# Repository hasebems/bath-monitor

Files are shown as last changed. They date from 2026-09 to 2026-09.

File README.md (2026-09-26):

# bath-monitor

5人家族の我が家では、お風呂に最後に入った人が湯船の水を抜いて洗うことになっています。しかし、その運用には以下の問題があります。
- まだ入ってない人がいるのに、湯船が空になって洗われていた
- もうみんな入ったのに、まだ入っていない人がいると勘違いして、そのまま朝まで湯船が洗われなかった

その後、入った人は磁石で印を付けるようにしたのですが、その運用は徹底されず、たびたびお風呂に関する問題が起き続けています。  

この bath-monitor はそんな家族の問題を解決するために開発しました。  
bath-monitor は以下の機能を持っています。
- 家族ごとに５つのボタンを搭載。ボタンが押されると LED が点灯し、ボタンごとに異なるメロディを鳴らす
- ボタンの押し間違いがあったら、二秒の長押しで LED は消灯し、キャンセルできる
- 照度センサーを搭載し、脱衣所が明るいか暗いかで誰かが入っていることをセンシングする
- ボタンとセンサーの信号はWi-Fi経由で自宅LAN上のFlaskサーバーに送られ、サーバーはライブダッシュボードを表示
- 携帯や PC でダッシュボードにアクセスすれば、誰が入ったか、今誰かが入っているかをリアルタイムに検知可能

設計の詳細は`docs/design.md`、HTTPの契約(プロトコル)は`docs/protocol.md`、ピン割り当ては`docs/wiring.md`を参照してください。embassy-rpのPIOの不具合の調査記録と回避策は`docs/embassy-rp-pio-drop-bug.md`にまとめています。

## サーバー

```bash
cd server
python -m venv .venv && source .venv/bin/activate
pip install -r requirements.txt
python app.py            # http://<this-machine>:8080
```

テスト: `pytest tests/ -q`(`server/`ディレクトリで、venvを有効化した状態で実行)。

Raspberry Pi上でsystemdサービスとして24時間365日稼働させる方法(`wsgi.py`経由の本番用WSGIサーバー、自動起動・自動再起動)は`docs/deploy.md`を参照してください。

## ファームウェア

`rustup target add thumbv8m.main-none-eabihf`(RP2350はArm Cortex-M33のため)と、書き込み用に`picotool`をPATHに通しておく必要があります(デバッグプローブ不要 — 書き込みはBOOTSEL + `picotool`で行います。`elf2uf2-rs`はRP2350/RP235xでは動作しません)。

```bash
cp firmware/src/secrets.rs.example firmware/src/secrets.rs   # 実際のWi-Fi/サーバー情報を記入
cd firmware
cargo build --release     # コンパイルチェックのみ
cargo run --release       # ビルドし、BOOTSELモードのPico 2 Wにpicotool経由で書き込み
```

ログはUSBシリアル経由(`screen /dev/tty.usbmodemXXXX 115200`)で確認します(RTT/defmtではありません)。

- `XXXX`の部分: Pico 2 WをUSB接続した状態で`ls /dev/tty.usbmodem*`を実行すると確認できる(複数のUSBシリアルデバイスが繋がっている場合は、抜き差し前後で`ls`の差分を見ると確実)
- `screen`の終了方法: `Ctrl-a`の後に`k`を押し、確認プロンプトで`y`を押す(`Ctrl-a` `d`はデタッチのみでプロセスは残るため注意)

## 現在の状況

- サーバーは実機のRaspberry Pi 4上にデプロイ・動作確認済み(ダッシュボードに自宅LAN上のスマートフォンからアクセスできることを確認済み)
- 対象基板は Pico W から Pico 2 W(RP2350) に変更となり、ファームウェアのコードはRP2350向けに移行済みです(`thumbv8m.main-none-eabihf`向けに`cargo clippy`まで通過)
- その後2026-09-19に実機のPico 2 Wへ書き込み、Wi-Fi接続、ボタン(1個目)、MAX98357Aアンプからのメロディ、オンボードLED、サーバーへの送信は動作を確認済み
- 照度センサーは、センサーを覆うとデバウンスされた在室状態が`POST /api/occupancy`で送られ、サーバーのダッシュボードにも在室と表示されることを確認済みです(2026-09-20)
- NeoPixelは、点灯・白の呼吸・長押し取り消しでの消灯を確認済みです。一方、残りのボタン(2〜5個目)と、押した人ごとの色は実機での動作確認がまだです — 確認すべき内容は`docs/design.md`の検証手順の節を参照してください。
- 照度センサーの浴室での明るさ(トリムポットのしきい値)の調整もまだです
- 現在はブレッドボード上での動作確認で、専用の基板を設計中です。基板が完成したら、`docs/design.md`の検証手順に沿って全機能をチェックする予定です

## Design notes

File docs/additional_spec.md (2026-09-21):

# 追加仕様

`docs/design.md`は実装済みの内容(ファイル名や、どのように実装したか)を記述する。このファイルには、今後追加していく外部仕様(何を実現したいか)を追記していく。実装が完了したら、該当項目を`docs/design.md`に反映し、この項目は残したうえで状態を「実装済み」に更新する。

## 雛形

新しい項目を追記するときは、この形式に合わせる(「未決定事項」は無ければ省略してよい)。

```markdown
## <機能名>

**状態:** 未定 / 検討中 / 確定(実装待ち) / 実装済み

**仕様:**
<実現したいことを記述>

**未決定事項:**
- <まだ決まっていない点があれば列挙>
```

---

## オーディオ: `WAVEFORM_BUFFER`への波形書き込み

**状態:** 実装済み(`waveform.rs`/`music.rs`。未決定事項のパラメータ調整とメロディ作成は実機での確認待ち)

**仕様:**

- 波形出力モジュールとして、波形出力用の slot を２個作成する
    - slot は、波形データの先頭から、位相情報に合わせてデータを読み込む
    - slot は、note on message を受信し、これをトリガにして波形を出力する
    - note on message には、pitch, volume, duration の３つのデータがある
        - pitch は、波形を読み込むための1サンプルあたりの位相情報を変更する(69で波形データを一つずつ読む位相となる)。MIDI Note Number 69(=A4=440Hz)を基準に、位相増分 = 2^((pitch - 69) / 12) として計算する
        - volume は、音量で 1-127 の範囲、振幅は (volume/127)^2 とする
        - duration は、音を消し始めるタイミングを制御する
    - slot に note on message が来たら、振幅ゼロから attack rate に従って、少しずつ振幅を上げていく
    - slot が鳴り始めて duration だけ経過したら最大振幅から release rate に従って、少しずつ振幅を下げていく
    - 振幅がある一定値以下(minimum level)になったら、振幅はゼロにする
    - 一つの slot が発音中に新しい note on message が来た時、現在の音を damp rate で急速に消音し、振幅が minimum level 以下になったら、attack rate に従って note on message を開始する
        - damp 中は前の音の pitch で、attack が始まったら新しい pitch で発音する
        - damp rate 中にさらに新しい note on message が来たら、次になる音を新しい note on message に差し替える
    - WAVEFORM_BUFFER のDMA転送が終わったことを確認できたら、AUDIO_BUFFER_SAMPLES 分の二つの slot のバッファの値を足して、その値を WAVEFORM_BUFFER に書き込む
        - 「DMA転送が終わったこと」の確認には Signal を使う。既存の DMA 転送ループ(`i2s.write().await` が返った直後)が Signal を発行し、波形出力モジュールはこれを待ってから次のチャンクを合成・書き込みする。Signal は最新の1回分の通知のみを保持するため、波形出力モジュールが多少速くても遅くても、実際の再生ペースと1:1でずれずに同期できる
    - バッファの値を足した結果がオーバーフローした場合、最大値に張り付く
- 音楽データ再生モジュールを作成する
    - 音楽データは、note on message の集まりであり、time, pitch, volume, duration の４つのデータを複数個持ったものである
        - time: 0 から始まり、再生開始からの時間を表す(1=10msec)
        - pitch: 0-127 の MIDI の Note Number
        - volume: 1-127
        - duration: この note on message が開始してから消音するまでの時間を、time と同じ単位で記述する
    - 読み出したデータは、note on message として二つの slot に交互に送られる
    - 音楽データは全部で５つある
    - このモジュールは、event によって再生開始し、event は 0-4 の値を持っており、その値で音楽データを指定する
    - ボタンを押すと、押したボタン(person_idx、0-4)に対応する音楽データが発音する。つまりボタンごとに別々のメロディが鳴る
    - モジュールが再生中に新しい event が来たら、引数に合った新しい音楽データを再生開始する
        - slot に対して消音するなど、特別な処理は特に行わない
- 波形出力モジュールと音楽データ再生モジュールは、同じ core 内で、別タスクとして実装する
- core0 から core1 に、音楽データ再生モジュールを駆動する event を送る仕組みを作成する(Channelを使用)
    - 実装済み: `music.rs::MELODY_CHANNEL`(`Channel<CriticalSectionRawMutex, usize, 8>`)を新設し、`buttons.rs`のボタン押下処理から person_idx を送信する(長押しによる取り消し時は、`music::CANCEL_MELODY`=5 を送り、専用の取り消し音を鳴らす)。CORE1側では音楽データ再生モジュール(`music.rs`の`music_task`)がこのチャネルを受信して再生を開始する
- 用意するデータ
    - slot 用の波形データ(一波分、サイン波、100サンプル) — 実装済み(`waveform.rs`の`WAVETABLE`)
    - 5つの音楽データ — 実装済み(`music.rs`の`MELODY_0`〜`MELODY_4`)。ただし現状はプレースホルダの短い旋律で、実際の曲ではない
- サンプリング周波数(`AUDIO_SAMPLE_RATE_HZ`)は 44,000Hz とする(一般的なオーディオ規格に合わせる必要がないため、440Hz(MIDI Note 69 = A4)の整数倍を採用)。これにより pitch=69 の波形テーブルがピッチ誤差ゼロで100サンプルぴったりになり、波形データの作成や、将来別の楽器/音色への転用がしやすくなる
- attack/release/damp の動作は、時間に対して一定割合で目標に近づく漸近的カーブとする
    - この「一定割合」は1サンプルごとに適用する(チャンク単位ではない)。RP2350のCPU性能に対して1サンプルごとの演算負荷は十分小さく(1サンプルあたり数千サイクルの余裕がある)、チャンク単位更新による振幅の階段状変化(zipper noise)を避けられるため

**未決定事項:**
- attack rate(現状は`config.rs`の`AUDIO_ATTACK_RATE`=0.01、実機で聴いて調整するまでの仮値)
- release rate(同`AUDIO_RELEASE_RATE`=0.002、仮値)
- damp rate(同`AUDIO_DAMP_RATE`=0.05、仮値)
- minimum level(同`AUDIO_MINIMUM_LEVEL`=0.001、仮値)
- 5つの音楽データの実際の旋律(現状はプレースホルダ)

---

## オンボードLEDのハートビート点滅

**状態:** 実装済み(`wifi.rs`。1Hzの点滅は実機で確認済み。接続試行中の点灯と失敗時の「ピピ」の見え方は未確認)

**仕様:**

- Raspberry Pi Pico 2 W基板上のオンボードLEDで、ファームウェアが動作していることと、Wi-Fi接続の成否を、基板を見るだけで確認できるようにする
- LEDの状態は次のとおりとする

| 状況 | オンボードLED |
|---|---|
| Wi-Fi接続試行(`join`)の実行中 | 点灯したまま |
| 接続試行に成功したあと(接続の監視中) | 1Hz(500ms点灯 / 500ms消灯)の点滅を続ける |
| 接続試行に失敗したあと(次の試行までの待機中) | 「ピピ」(短い点滅2回のあと、しばらく消灯)を繰り返す |

- 失敗の「ピピ」は、接続試行が失敗した直後から始め、次の接続試行が始まる(LEDが点灯に変わる)まで繰り返す。接続に失敗し続けている間は、「点灯 → ピピ、ピピ、…(次の試行まで) → 点灯 → …」の繰り返しになり、成功後の1Hzの点滅とは見分けがつく
- 1Hzの点滅は、接続試行に成功していれば続ける。サーバーとの通信の成否とは無関係で、サーバーが停止していても点滅する
- オンボードLEDはRP2350のGPIOではなくWi-FiチップCYW43439のGPIO0(`WL_GPIO0`)に接続されているため、cyw43の`Control`経由で制御する。外部配線は不要で、`docs/wiring.md`のGPIO割り当てとも競合しない
- 接続試行の実行中に点灯したままにするのは、`join`が`Control`を占有し、完了まで戻らないため。cyw43の`join`自体にはタイムアウトがなく、チップが結果を返さないと永久に戻らないため、ファームウェア側で一定時間(`WIFI_JOIN_TIMEOUT_SECS`)を超えた接続試行を打ち切り、失敗として扱う(この場合の「ピピ」も同じ)。実機で、`join`が戻らずLEDが点灯したままになる現象を確認したための対応
- LEDの制御はCORE0のエグゼキュータ上で、`Control`を所有するタスクが行う。`Control`は`&mut`でしか使えず、Wi-Fiの接続/再接続処理も同じ`Control`を使うため、LED専用タスクは持たず、Wi-Fi管理タスク(下記)が兼ねる。CORE0のエグゼキュータが動かなくなった場合(`panic-halt`によるパニック停止を含む)は、LEDの動きが止まる(点灯か消灯のまま固まる)ため、異常の検知にも使える。CORE1(オーディオ)が動いているかどうかは反映しない

**未決定事項:**
- 接続試行のタイムアウト(`WIFI_JOIN_TIMEOUT_SECS`=20秒)は仮の値。なお、実機で、起動直後の最初の`join`が戻らず、タイムアウト後の2回目で接続できることを確認した(2026-09-19)。戻らない原因(ルーターの認証方式(WPA2/WPA3)や設定との相性、チップの初期化直後の状態など)は未特定で、タイムアウトは症状への対処であり、原因の解消ではない。起動のたびに起きるなら、接続まで約20秒余分にかかる
- 各パターンの時間は仮の値で、実機で見て変更してよい(`config.rs`)。1Hzの点滅(`ONBOARD_LED_BLINK_HALF_PERIOD_MS`=500)、「ピピ」の1回分の点灯/消灯(`ONBOARD_LED_FAIL_FLASH_MS`=100)、「ピピ」の繰り返しの間隔(`ONBOARD_LED_FAIL_PATTERN_GAP_MS`=1600)
- 接続試行に成功したが、まだDHCPが完了していない間(`wifi::is_connected()`はまだ`false`)も、成功として1Hzで点滅する

---

## Wi-Fi接続状態に依存しない動作

**状態:** 実装済み(`wifi.rs`/`outbox.rs`/`http_client.rs`/`status_poll.rs`ほか。実機で確認済み: 接続後のボタン押下がサーバーに届くこと、接続が完了する前の押下が接続後に届くこと、照度センサーによる在室の送信とサーバーのダッシュボードへの反映(2026-09-20)。未確認: 切断後の再接続、オフライン中・サーバー停止中の押下の再送、NeoPixelの同期)

**仕様:**

- 基本方針: すべてのハードウェア(ボタン、NeoPixel、オーディオ、照度センサー、オンボードLED)は、Wi-Fiが接続されているか否かに関わらず、起動直後から動作する。Wi-Fi接続の完了を待って他のタスクの起動を遅らせることはしない(現状は`net::init`が接続完了まで戻らず、その間ボタン等が一切動かないため、これを改める)
- Wi-Fiの接続状態を表すグローバル変数を設ける
    - 「接続済み」は、リンクが上がっており、かつDHCPによるIPアドレス取得が完了した状態とする(`join`に成功しただけでは接続済みとしない)
    - 切断を検知したら「未接続」に戻す
    - 更新するのはWi-Fi管理タスクだけとし、ほかのタスクは読み取るだけにする。送信を行うタスクが、接続済みになるのを待てる形にする
- 未接続の間は、サーバーへのメッセージ(`POST /api/press`、`POST /api/occupancy`、`GET /api/led-state`)を送らない
- Wi-Fi管理タスクを設け、`cyw43::Control`を所有させる
    - 起動時にWi-Fiへ接続する。失敗時は指数バックオフでリトライする(現状の`net.rs`と同じ)
    - 接続後に切断を検知したら再接続する(現状は起動時に1回`join`するだけで、切断後は誰も再接続しないため、ルーターの再起動などで一度切れると電源を入れ直すまで送信できない)
    - オンボードLEDの点滅(前項「オンボードLEDのハートビート点滅」)も兼ねる
- ローカルの動作(NeoPixelの点灯、メロディの再生)は、ネットワークの状態、送信の成否、送信待ちの状態のいずれにも依存しない。ボタン押下の処理はローカルの反応を先に行い、ネットワーク側の処理で待たされないようにする(現状は、送信待ちのチャンネルが満杯になるとボタンタスクが止まり、LEDもメロディも出なくなる)
- ボタン押下の扱い
    - 人ごとの「未送信」の状態(5人分)として保持する。キューではないので溢れず、同じ人の複数回の押下は1つにまとまる(サーバー側も同日中の再押下は冪等)
    - 接続済みの間、送信タスクは未送信の人を順に`POST /api/press`し、2xxが返ったら未送信を下ろす。失敗(接続失敗、タイムアウト、5xxなど)したら未送信のまま残し、一定間隔で再試行する。Wi-Fiは接続済みでサーバーだけが停止している場合も同様に再送する(従来は失敗しても捨てていたため、Wi-Fiが生きていても押下が失われた)
    - 4xxが返った場合(人物IDの不一致など)は、再送しても成功しないため、ログに残して破棄する
    - 押した直後のNeoPixel点灯は、Wi-Fiの状態に関わらず行う
    - `/api/led-state`による同期(Sync)は、未送信の人のLEDを消さない(未送信の操作が求める状態を、サーバー状態より優先して表示する。長押しによる取り消しについては「ボタン長押しによる押下の取り消し」を参照)。これがないと、オフライン中に押した人のLEDが再接続後の同期で消えてしまう
- 在室(照度センサー)の扱い
    - 最後にサーバーへ送信成功した在室状態を保持する。現在値がそれと異なる場合に限り、接続済みの間に現在値を送る
    - オフライン中の途中の変化(例: 入室→退室)は失われる
    - 起動直後は最後に送信した値が不明なため、従来どおり、最初の変化があるまで送らない
    - 4xxが返った場合は、押下と同様にログに残して破棄する
- サーバーへの送信は、必ずタイムアウトして戻ること(相手に届かない場合に、送信タスクが長時間止まらないようにする)
- 許容する制限
    - サーバーが受理したのに応答がタイムアウトした場合、同じ内容を再送する。押下は冪等なので影響はないが、在室は同じ状態が2回記録されうる(サーバーが重複排除をしないため)
    - サーバーは受信した時刻を記録し、基板には時計がないため、オフライン中の押下や在室変化の記録時刻は、送信に成功した時刻になる。深夜0時をまたいで送信された押下は、翌日の記録になる
    - オフラインで起動した場合、既に押した人のNeoPixelも、最初の同期に成功するまでは消灯のままになる(基板に永続ストレージがないため)。その間に再度押しても、同日中の押下は冪等で害はない
    - 送信に必要な`embassy_net::Stack`はWi-Fi接続前に作成できるため、送信/同期タスクは起動時に生成し、接続済みになるまで待機させる

**未決定事項:**(現状の実装での扱いを併記)
- 未送信の押下を保持し続ける期限 — 現状は無期限。長時間オフラインだった後の送信は、実際の押下とは別の日の記録になりうる
- 起動直後の在室状態を、最初の接続時に一度サーバーへ送るかどうか — 現状は送らない。サーバーは重複排除をしないため、送ると再起動のたびに在室ログが1行増える一方、送らないと再起動後に最初の変化があるまでサーバー側の在室状態が実際とずれる可能性がある
- 送信のタイムアウト値、再試行間隔、再接続後のリンク待ち猶予 — 現状は`config.rs`の`SERVER_REQUEST_TIMEOUT_SECS`=10、`SEND_RETRY_INTERVAL_SECS`=5、`WIFI_LINK_UP_GRACE_SECS`=10。いずれも仮の値で、実機で確認して調整する
- 切断後の再接続は、`leave`を挟まずに`join`を呼び直している(実機では未確認。接続試行がタイムアウトした後は`leave`を挟んで再試行し、その2回目で接続できることを実機で確認した)

---

## ボタン長押しによる押下の取り消し

**状態:** 実装済み(`buttons.rs`/`outbox.rs`/`http_client.rs`/`status_poll.rs`/`led.rs`/`music.rs`、サーバーは`POST /api/cancel`。`cargo build --release`/`cargo clippy --release`とサーバーのテストは通過。実機で確認済み: 長押しで取り消し音が鳴り、NeoPixelが消え、Pi上のサーバーのダッシュボードが「Not yet」に戻ること(2026-09-19)。未確認: オフライン中・サーバー停止中の取り消しの再送)。当初は「押した瞬間に登録し、長押しで取り消す」方式だったが、長押しのときも押下のメロディが鳴ってしまうため、「離した時点で登録する」方式に改めた

**仕様:**

- ボタンを押し続けると、その人の「今日の押下」を取り消して、押していない状態に戻せる。押し間違いの訂正や、動作確認中のリセットに使う(従来は翌日0時まで消せなかった)
- 押下として登録するのは、ボタンを押してから`BUTTON_LONG_PRESS_MS`(2000ms)以内に離した時点とする。離したときに、NeoPixel点灯、メロディ、`POST /api/press`を行う(押している間は何も起きない)
- `BUTTON_LONG_PRESS_MS`以上押し続けると、離すのを待たずにその時点で取り消しとみなす。押下のメロディは鳴らさず(取り消し音と混ざらないように)、次だけを行う
    - その人のNeoPixelを消す
    - 取り消し用の音(専用のメロディ`CANCEL_MELODY`、押下のメロディとは別の低く下がる2音)を鳴らす
    - `POST /api/cancel`を送る(サーバーは`last_pressed_at`/`last_pressed_date`をNULLに戻す。冪等)
    - 押したままの間は、離したときに新たな押下と扱わない(離すまで待つ)
- 押していない状態から長押ししても、押していない状態のまま変わらない(取り消し音は鳴る)
- 送信の扱いは押下と同じ。人ごとの未送信の状態は「最後の操作(押下か取り消し)」だけを保持し、未送信の押下の後に取り消しがあれば取り消し1回にまとまる。Wi-Fi非接続時やサーバー停止時も、接続後に再送される
- `/api/led-state`による同期(Sync)は、未送信の操作がある人については、その操作が求めるLEDの状態(押下なら点灯、取り消しなら消灯)を優先する。サーバーの状態は、未送信の操作がない人にだけ反映する
- 4xxが返った場合は、他の送信と同様にログに残して破棄する。古いサーバー(`/api/cancel`が未実装で404を返す)に対しては、取り消しは届かず、次の同期でLEDが再点灯する。サーバーを先に更新してからファームウェアを書き込むこと

**許容する制限:**
- 取り消しが未送信のまま基板を再起動すると、その取り消しは失われる(未送信の状態はRAMのみで保持するため)。押下の場合と同じ

**未決定事項:**
- 長押しの時間 — 現状は`config.rs`の`BUTTON_LONG_PRESS_MS`=2000。仮の値で、実機で確認して調整する。なお押下の反応(LED・メロディ)は離した時点になるため、ボタンを押している間は無反応になる(押し続けても2秒経つまで何も返らない)
- 取り消し音 — 現状は`music.rs`の`MELODY_CANCEL`(プレースホルダ)

---

## NeoPixelの定期書き込みと見え方

**状態:** 実装済み(`led.rs`/`led_pattern.rs`、`config.rs`の`NEOPIXEL_FRAME_INTERVAL_MS`。`cargo build --release`/`cargo clippy --release`は通過。実機で確認済み: 10fpsの書き込み(2026-09-19)。押していない人の白の呼吸(6秒周期)も実機で確認済み(2026-09-19)。その後(2026-09-20)、状態(押下・在室)の保持を`led.rs`から`led_pattern.rs`に移し、イベント用のチャンネル(`LED_CHANNEL`)をやめて、最新の値で上書きする共有状態にし、呼吸の位相をLEDごとにずらして光が流れるようにし、照度センサーが on の間だけ呼吸させるよう変更した — ビルドとclippyは通過、実機では未確認。押した人の人ごとの色も実機では未確認)

**仕様:**

- 動機: 従来はイベントがあったときだけNeoPixelのデータ線に信号が出るため、オシロで1回きりのバーストを捉えるのが難しく、配線や回路の確認がしづらかった。また、ノイズ等でLEDの表示が乱れても、次のイベントまで直らなかった
- NeoPixelは、固定のフレーム周期`NEOPIXEL_FRAME_INTERVAL_MS`(100ms、つまり10fps)で、変化の有無にかかわらず毎フレーム、5個ぶんをチェーンに書き込む。ボタン操作や`/api/led-state`による同期のイベントは、書き込みのタイミングを早めず、人ごとの押下状態を更新するだけにする。その変化は、次のフレーム(最大100ms後)に反映される
- ソフトウェアの構造を、次の2つに分ける。状態の保持を含め、何を見せるかはすべて`led_pattern.rs`にあり、`led.rs`は状態も色も知らない
    - 何を見せるか(`led_pattern.rs`): 状態(人ごとの押下状態、在室状態)と見え方をまとめて担当する。状態は共有データとして持ち(`outbox.rs`と同じく、キューではない)、ボタン・`status_poll`・`occupancy_task`が`set_pressed`/`set_all_pressed`/`set_occupied`で最新の値に上書きする(待たされず、後の書き込みが勝つ)。毎フレーム`frame(now_ms)`が、そのときの状態から1フレームぶんの色を返す。色の決定そのもの(押下状態・在室状態・時刻 → 色)は純粋関数`render`で、ハードウェアには依存しない。色・呼吸の周期・明るさなど、点灯のしかたやそれが依存する状態を変えるときは、このファイルだけを変更する(`config.rs`には見え方に関する定数を置かない)
    - 出力(`led.rs`): PIOによるWS2812への書き込みと、固定周期のフレームループだけ。毎フレーム`led_pattern::frame`が返した色を書く
- 現在の見え方(`led_pattern.rs`)
    - 押下済みの人: 人ごとに決めた色で点灯し続ける(点滅しない)。色は`led_pattern.rs`の表`PRESSED_COLORS`(`config::PEOPLE`と同じ順)で設定する。初期値は、grandpa=青(0,0,48)、grandma=ピンク(40,0,20)、father=緑(0,40,0)、mother=オレンジ(48,16,0)、son=黄(40,28,0)。5色は互いに異なり、押していない人の白と紛らわしくならないよう白っぽい色は避けている
    - まだ押していない人(在室、つまり照度センサーが on のときだけ): 白で、だんだん明るく、だんだん暗くを`BREATH_PERIOD_MS`(6000ms)周期で繰り返す(呼吸)。明るさは三角波を2乗した値(最大は各色`BREATH_PEAK`=16)で、目で見て明るさが均等に変わるようにしている。位相は時刻から計算するため、フレーム周期に依存しない
    - 光が流れる見え方: 呼吸の位相を、チェーンの順(`config::PEOPLE`と同じ順)に、1個ごとに`BREATH_PHASE_STEP_MS`(1000ms)ずつ遅らせる。これにより、明るい部分がLED 0から最後のLEDに向かって横に流れて見える(先頭から末尾までで4秒、周期の約67%)。流れる向きを逆にしたいときは、`render`でLEDの番号を末尾から数える。0にすれば全員が同じ位相に戻る。位相のずれはLEDの位置(チェーン上の番号)で決まるため、間の人が押して点灯していても、残りの人の流れ方は変わらない
    - 不在(照度センサーが off)のとき: まだ押していない人のLEDは消灯する。押した人は、在室かどうかに関わらず、人ごとの色で点灯し続ける(その日の記録であるため)
    - 在室状態の受け渡し: `occupancy_task`が、起動直後の読み取り値(デバウンスなし。`Debouncer`は変化しか返さないため)と、以降のデバウンス済みの変化を、`led_pattern::set_occupied`で渡す。サーバー送信用の`outbox`の扱いは変えない(起動直後の値は、従来どおり送らない)。`led_pattern`の状態は、最初の値が入るまでは不在として扱う

**未決定事項:**
- 押した人の5色の選び方 — 仮の値。実機で見て、区別しやすさと明るさを見て調整する(特にWS2812の青は他の色より暗く見えやすい)
- 呼吸の周期(6秒)・最大の明るさ・最も暗いときの明るさ(現状は完全に消える。最小値を設ける場合は`breath_color`を変える)・位相のずれ`BREATH_PHASE_STEP_MS`(1000ms)は、実機で見て調整する。また、LEDが実際に並ぶ向き(筐体の左右)と、光の流れる向きが合っているかも、筐体ができてから確認する

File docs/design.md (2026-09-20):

# 設計: bath-monitor — 「誰がお風呂に入ったか」を記録する家庭用IoTシステム

## 背景・目的
`bath-monitor`は、浴室の壁に取り付けるパネルで、5個の押しボタン(家族一人につき1個)と1個の在室用照度センサーを備え、Raspberry Pi Pico 2 Wに配線されています。あわせて、各ボタンに対応するNeoPixel(その人が今日押していれば点灯)と、ボタン押下時にその人専用のメロディを鳴らすI2Sアンプ(MAX98357A)+スピーカーも搭載します。ボタンを押すと「この人物は今日入浴した」という記録が残ります(1日単位で冪等、ローカル時刻の深夜0時にリセット。押し間違いなどは、ボタンの長押しで取り消せる) — 目的はあくまで今日誰が押した/押していないかを把握することであり、「最後に入ったのは誰か」を計算することではありません。照度センサーは独立して浴室が現在使用中かどうかを報告し、その入退室の履歴は恒久的にログとして保持されます。Pico 2 Wはどちらの信号も、MQTTではなく単純なHTTP POSTで自宅LAN上のFlaskサーバーに送信し、サーバーは自動更新される単一のHTMLダッシュボードを描画します。

**基板の変更履歴**: 当初の実装(以下参照)は元のPico W(RP2040)を対象としていましたが、ファームウェアを実機に一度も書き込む前の2026-09-03に、対象基板をPico 2 W(RP2350)へ変更する方針となり、同日中にファームウェアのコードもRP2350向けに移行しました(`thumbv8m.main-none-eabihf`向けにビルドとclippyの両方を通過済み。その後、2026-09-19に実機のPico 2 Wへ書き込み、Wi-Fi接続、ボタン、メロディ、オンボードLED、サーバーへの送信の動作を確認済み。未確認の項目は`CLAUDE.md`の「Notes for future work」を参照)。Pico 2 Wはピン互換(GPIO番号が同じ)のため、配線・ピンの計画には影響がありませんでした — マイグレーションの詳細な差分(ターゲットのtriple、`embassy-rp`のfeatureフラグ、ブートイメージ形式、書き込みツール、クロック分周比)については`CLAUDE.md`の「Notes for future work」を参照してください。

初期(Pico W)実装時に開発機(macOS)で使用したツールチェーン: rustc/cargo 1.93.0、`thumbv6m-none-eabi`ターゲットをインストール済み、`elf2uf2-rs`/`flip-link`/`cargo-generate`をPATHに追加(`probe-rs`は未使用 — 書き込みはSWDデバッグではなくBOOTSEL + UF2のドラッグ&ドロップで行う)。Python 3.14.6/pip 26.1.2。RP2350/Pico 2 Wへの移行後: `thumbv8m.main-none-eabihf`ターゲット、書き込みには`elf2uf2-rs`の代わりに`picotool`を使用(`elf2uf2-rs`はRP235x向けの動作するUF2を生成できないため)、リンカとしての`flip-link`はこのターゲットでも引き続き動作することを確認済み。

## リポジトリ構成
1つのリポジトリに2つの独立したプロジェクトが存在します(Cargoワークスペースではなく、Rustのクレートは1つだけ):
```
bath-monitor/
├── CLAUDE.md, README.md, .gitignore
├── docs/design.md           # このファイル(実装済みの内容)
├── docs/additional_spec.md  # 追加していく外部仕様(実装後も項目は残し、状態を更新する)
├── docs/protocol.md         # 正式なHTTP APIの契約(両側の信頼できる情報源)
├── docs/wiring.md           # GPIOピン・PIO/DMAの割り当て
├── docs/deploy.md           # Raspberry Pi 4へのサーバーのデプロイ手順(systemd)
├── firmware/                 # Rust、embassy-rp、独立したクレート
├── schematic/                # KiCadの回路図/基板データ
└── server/                   # Python、Flask
```

## ファームウェア(`firmware/`、Rust + embassy-rp + cyw43)

**主な設計判断:**
- ロギング: `defmt`/RTTではなく`embassy-usb-logger`(USB-CDC)+ `log` — デバッグプローブが手元にないため。ただし書き込みに使うのと同じケーブル経由でUSBシリアルが使える。
- パニックハンドラ: `panic-halt`(RTTベースの`panic-probe`はプローブなしでは意味がないため)。
- 設定: `src/secrets.rs`(gitignore対象、実際のWi-Fi/サーバー情報)+ `src/secrets.rs.example`(コミットされているテンプレート)+ `src/config.rs`(非秘匿情報: 人物リスト、GPIOピン、デバウンス時間など)。
- HTTPペイロード: `heapless::String` + `core::write!`による手作りの小さなJSON(`serde`は使わない — ボディはせいぜい1〜2フィールドのため)。
- タスク間の連携: チャンネルは、CORE1のメロディ再生用の`MELODY_CHANNEL`(コアをまたぐ)だけを、受け取る側の`music.rs`に用意する。NeoPixelの表示に必要な状態(人ごとの押下、在室)は、チャンネルではなく`led_pattern.rs`の共有状態として保持し(最新の値で上書きするだけで、キューも待ちもない)、サーバーへ送るデータも同様に`outbox.rs`の状態(人ごとの未送信の押下/取り消し、在室の現在値/最後に送信した値)として保持し、単一の`sender_task`が`reqwless::HttpClient`を所有して、Wi-Fi接続中に直列で送信する(ロック不要で、自然にPOSTがレート制限される)。ボタン/在室タスクは`outbox`に記録するだけで決してブロックしない。
- Wi-Fi非依存の動作(`docs/additional_spec.md`「Wi-Fi接続状態に依存しない動作」): ボタン、NeoPixel、オーディオ、照度センサーは、`main.rs`でWi-Fiチップの初期化より前に起動し、Wi-Fiの接続状態に関わらず動作する。Wi-Fiの接続状態はグローバル(`wifi::is_connected()`、リンクアップかつDHCP完了で`true`)で表し、Wi-Fi管理タスク`wifi_task`だけが更新する。サーバーへの送信/同期は、これが`true`の間だけ行う。オフライン中(またはサーバー停止中)の押下は`outbox`に未送信として残り、届くまで再送される。同期(`status_poll.rs`)は未送信の人のLEDを消さない。在室は最後に届けた値と異なる場合だけ、現在値を1回送る。
- オーディオ出力: RP2350の2コア目(CORE1)専属で実行(`audio.rs`、`embassy_rp::multicore::spawn_core1`で起動)— PIO2 + DMA_CH3経由のI2S(`embassy_rp::pio_programs::i2s`、GPIO16=BCLK/GPIO17=LRC/GPIO18=DIN、MAX98357Aアンプ宛)によるリアルタイムDMA供給ループを、CORE0側のネットワーク/LED/ボタン処理の遅延から切り離すため。256サンプルの共有バッファ`WAVEFORM_BUFFER`(`CriticalSectionRawMutex` — embassy-rpのSIOハードウェアスピンロック実装によりコア間で安全)の内容を、CORE1が無限ループで読み出しては`i2s.write().await`し続ける設計。バッファへの書き込みは`waveform.rs`が担い、`i2s.write().await`完了ごとに`Signal`(`audio::BUFFER_CONSUMED`)で駆動されることで実際の再生ペースと1:1で同期している(`docs/additional_spec.md`参照)。
- オーディオ合成: 2 slotのサイン波オシレータ+振幅エンベロープ(attack/release/damp、いずれも「1サンプルごとに目標値へ一定割合で近づく」漸近カーブ)からなる`waveform.rs`のシンセと、5つの固定メロディを`music::MELODY_CHANNEL`(ボタン押下由来のperson_idx)をトリガに再生する`music.rs`の2モジュール構成。サンプリング周波数を意図的に非標準の44,000Hz(=440Hz×100)にすることで、MIDI Note 69(A4=440Hz)がピッチ誤差ゼロで100サンプルの波形テーブルにちょうど一致するようにしてある。attack/release/damp rateとminimum levelは`config.rs`に仮値を置いているだけで実機での聴感調整待ち、5つのメロディ自体もプレースホルダ(`CLAUDE.md`のNotes for future work参照)。

**依存クレートのバージョン**(2026-08-30時点でcrates.ioの実際のリリースに対して検証済みで、`firmware/Cargo.lock`で固定。これらのクレートはバージョンによってAPIの形が変わるため、上げる場合は`~/.cargo/registry/src/`の実ソースと突き合わせて確認すること — 詳細は`CLAUDE.md`の「Notes for future work」を参照):
```
embassy-executor 0.10.0, embassy-time 0.5.1, embassy-rp 0.10.0,
embassy-net 0.9.1 (tcp, dns, dhcpv4), embassy-sync 0.8.0, embassy-usb-logger 0.6.0,
cyw43 0.7.0, cyw43-pio 0.10.0, smart-leds 0.4.0,
reqwless 0.14.0, embedded-io-async 0.7.0,
cortex-m 0.7.9, cortex-m-rt 0.7.6, panic-halt 1.0.0,
static_cell 2.1.1, heapless 0.9.3, log 0.4.34, portable-atomic 1.15.0 (critical-section)
```

**モジュール構成:**
- `main.rs` — エグゼキュータのセットアップ、ハードウェア初期化、全タスクのスポーン。起動順は、(1) NeoPixel/オーディオ/在室/ボタンのタスク(Wi-Fiに依存しない)、(2) `net::init`(Wi-Fiチップとスタックの初期化)、(3) `wifi_task`/`sender_task`/`status_poll_task`
- `secrets.rs` / `secrets.rs.example` / `config.rs` — 上記の通り
- `irqs.rs` — `bind_interrupts!`で`PIO0_IRQ_0`/`PIO1_IRQ_0`/`PIO2_IRQ_0`/`DMA_IRQ_0`/`USBCTRL_IRQ`のハンドラを一箇所にまとめて定義(embassy-rpでは全DMAチャンネルが`DMA_IRQ_0`に固定で、チャンネルごとのIRQ選択はできない)
- `debounce.rs` — `buttons.rs`/`occupancy.rs`で共有する`Debouncer`: `wait_for_any_edge()`で変化を検知し、指定時間後もレベルが変わったままなら確定とみなす(チャタリングは静かに無視する)
- `net.rs` — cyw43とembassy-netスタックの初期化のみ(Wi-Fiへの接続はしない)。`(Stack, cyw43::Control)`を返し、`Control`は`wifi_task`に渡される。`Stack`は接続前から作成でき、DHCPはリンクが上がれば自動で進む 注意: embassy-rp 0.10.0のPIOは、利用者数と使用ピンの記録がPIO0/1/2で共有される不具合があり、未使用の`Common`/`StateMachine`をdropすると全PIOのピンが機能なし(NULL)に戻ってしまう(NeoPixelのピンが消えた原因)。そのため、`net.rs`・`led.rs`・`audio.rs`は、未使用の部分を`core::mem::forget`でdropさせない(詳細は`CLAUDE.md`)
- `wifi.rs` — Wi-Fi管理。`cyw43::Control`を所有する`wifi_task`が、`join`(指数バックオフ付きリトライ、一時的なAPの不調から自力で復旧できる必要がある — 動かなくなった基板をデバッグするプローブがないため)、接続後のリンク/DHCP状態の監視、切断時の再`join`を行い、その結果をグローバルの`is_connected()`(`AtomicBool`)に反映する。未接続→接続済みになるたびに、`WIFI_UP`(`status_poll.rs`用)と`outbox::WORK`(`sender_task`用)を`Signal`する。オンボードLED(`WL_GPIO0`、Pico 2 WのオンボードはRP2350のGPIOではなくCYW43439のGPIO0で、`Control`経由でしか制御できず、`join`も同じ`Control`を`&mut`で使うためこのタスクが兼ねる)は`join`の結果を表示する。`join`実行中は点灯を保持し(`join`は完了まで戻らないうえcyw43側にタイムアウトがないため、`config::WIFI_JOIN_TIMEOUT_SECS`(20秒)を超えたら打ち切って失敗として扱い、`leave`してから再試行する)、成功後の接続監視中は`config::ONBOARD_LED_BLINK_HALF_PERIOD_MS`(500ms)ごとに反転して1Hzで点滅し、失敗後のバックオフ待ちの間は「ピピ」(`ONBOARD_LED_FAIL_FLASH_MS`=100msの点灯/消灯を2回、`ONBOARD_LED_FAIL_PATTERN_GAP_MS`=1600msの消灯を挟んで繰り返す)を出して、次の`join`で点灯に戻る。CORE0のエグゼキュータ上で動くため、CORE0が停止/パニックするとLEDの動きが止まり、生存確認になる。CORE1(オーディオ)やサーバー通信の成否は反映しない
- `outbox.rs` — サーバーへ届けるべきものの状態。押下/取り消しは人ごとに「状態語(操作のたびに増えるカウンタ+取り消しフラグ)」と「サーバーが受理した状態語」(不一致=未送信で、フラグが押下か取り消しかを表す。送信中に操作されても取りこぼさず、最後の操作だけが送られる)、在室は「最新の確定値」と「最後に届けた値」。`mark_press`/`mark_cancel`/`set_occupancy`は`WORK`(`Signal`)を発行するだけで決してブロックしない。`next()`が次に届けるものを返し、`complete()`で完了にする
- `buttons.rs` — `Debouncer`を使った5個の非同期タスク(pool_size=5)、ピンごとに50msでデバウンスし、押下確定後、`config::BUTTON_LONG_PRESS_MS`(2000ms)以内に離されたら(`with_timeout`で`Debouncer::debounce`を待つ形)押下として`outbox::mark_press`(サーバー送信用の記録、非ブロッキング)、`led_pattern::set_pressed(idx, true)`(LED点灯用)、`MELODY_CHANNEL`へのperson_idx送信(そのボタンに対応するメロディの再生トリガ、`docs/additional_spec.md`参照)を行う。離されないまま経過したら取り消しとみなし(押下メロディは鳴らさない)、`outbox::mark_cancel`、`led_pattern::set_pressed(idx, false)`(LED消灯)、`MELODY_CHANNEL`への`CANCEL_MELODY`送信を行って、離すまで待つ
- `occupancy.rs` — 照度センサーの読み取り(要件通りデジタル`Input`による2値信号)、`Debouncer`でしきい値付近のチャタリングを排除(約2000ms)してから`outbox::set_occupancy`で最新値を記録し、同じ値を`led_pattern::set_occupied`でNeoPixelにも渡す(起動直後の読み取り値も、デバウンスなしでNeoPixelにだけ送る)
- `http_client.rs` — 単一の`reqwless::HttpClient`を所有する`sender_task`が、`outbox::WORK`で起こされ、`wifi::is_connected()`の間だけ`outbox::next()`の内容を`/api/press`・`/api/cancel`に`{"person":"grandpa"}`、`/api/occupancy`に`{"occupied":true}`としてPOSTする。1リクエストは`config::SERVER_REQUEST_TIMEOUT_SECS`(10秒)でタイムアウトする。2xxなら完了、4xx(人物ID不一致など)はログに残して破棄、それ以外(接続失敗、タイムアウト、5xx)は未送信のまま`config::SEND_RETRY_INTERVAL_SECS`(5秒)後に再試行する
- `led.rs` — WS2812 NeoPixelチェーン(PIO1 + DMA_CH2、GPIO15、`config::PEOPLE`と同順)を所有し、出力だけを担当する。書き込みは`config::NEOPIXEL_FRAME_INTERVAL_MS`(100ms、10fps)の固定周期で、変化がなくても毎フレーム5個ぶんを、`led_pattern::frame`が返した色で書く(`Timer::at`で次のフレームの時刻まで待つ。状態の変化で書き込みが早まることはなく、変化は1フレーム以内に反映される)。色や点滅だけでなく、状態がどこから来るかも扱わず、すべて`led_pattern`に任せる
- `led_pattern.rs` — NeoPixelに何を見せるかのすべて。人ごとの押下状態と在室状態を、共有の状態(`Mutex<CriticalSectionRawMutex, Cell<…>>`)として持つ。更新は、最新の値で上書きする関数を直接呼ぶだけ(キューではないので、待たされることも溢れることもなく、後の書き込みが勝つ): `set_pressed(idx, bool)`(ボタンの押下/取り消し)、`set_all_pressed`(`status_poll.rs`から全員分を一括反映 — サーバーの日次リセット後にLEDを消す役目もこれが担う)、`set_occupied`(在室状態)。`frame(now_ms)`が、そのときの状態から1フレームぶんの色を返す。色の決定は、押下状態・在室状態と時刻だけから決まる純粋関数`render`(ハードウェア非依存)。現状は、押下済みの人が人ごとの色(表`PRESSED_COLORS`、`config::PEOPLE`と同順)で点灯し続け、押していない人は、在室(照度センサーが on)のときだけ、白で6秒周期(`BREATH_PERIOD_MS`)でだんだん明るく/暗くを繰り返し(呼吸の位相は`now_ms`から計算し、LEDごとに`BREATH_PHASE_STEP_MS`ずつずらして光が横に流れるように見せる)、不在のときは消灯する。色や周期などの見え方に関する定数は`config.rs`ではなくこのファイルに置き、見え方を変えるときは、このファイルだけを変更する
- `status_poll.rs` — Wi-Fi接続中に`GET /api/led-state`を`config::LED_SYNC_INTERVAL_SECS`ごと(および接続が復帰した直後)にポーリングし、結果を`led_pattern::set_all_pressed`で反映(リクエストは`SERVER_REQUEST_TIMEOUT_SECS`でタイムアウト)。サーバーがまだ知らない操作(`outbox`で未送信の押下/取り消し)がある人は、サーバーの答えではなくその操作が求める状態(押下なら点灯、取り消しなら消灯)のままにする。これがサーバー側の日次リセットや、ファームウェア再起動後の状態復元を反映させる仕組み
- `audio.rs` — CORE1専属でMAX98357A向けI2S出力(PIO2 + DMA_CH3、GPIO16=BCLK/GPIO17=LRC/GPIO18=DIN、`embassy_rp::pio_programs::i2s`)を行う。`embassy_rp::multicore::spawn_core1`でCORE1を起動し、`core1_task`(256サンプルの共有バッファ`WAVEFORM_BUFFER`を無限ループで読み出し`i2s.write().await`し続ける)、`waveform::waveform_task`、`music::music_task`の3つをその上にスポーンする。`core1_task`は`i2s.write().await`完了ごとに`Signal`(`BUFFER_CONSUMED`)を発行し、`waveform_task`はこれを待ってから次のチャンクを合成・書き込みすることで、実際の再生ペースと1:1で同期する
- `waveform.rs` — 「波形出力モジュール」(`docs/additional_spec.md`)。100サンプルのサイン波テーブル(`AUDIO_SAMPLE_RATE_HZ`=44,000Hzで、MIDI Note 69=A4=440Hzがピッチ誤差ゼロでちょうど1周する長さ)と、MIDIノート番号ごとの固定小数点(Q16)位相増分テーブル`PITCH_STEP_Q16`(`2^((pitch-69)/12)`から生成)を持つ。2つのslot(`Slot`構造体、状態はIdle/Attack/Release/Damp)を`waveform_task`が所有し、`SLOT_CHANNELS[0]`/`[1]`(`music.rs`から送られる`NoteOn`)を受けて発音、`BUFFER_CONSUMED`で駆動されるたびに`AUDIO_BUFFER_SAMPLES`分を1サンプルずつ合成・加算(オーバーフロー時は`i16`範囲にクランプ)して`WAVEFORM_BUFFER`に書き込む
- `music.rs` — 「音楽データ再生モジュール」(`docs/additional_spec.md`)。`config::PEOPLE`と同順の5つの固定メロディ(`NoteEvent{time, pitch, volume, duration}`の配列、現状はプレースホルダの短い旋律)を持つ`music_task`が、`MELODY_CHANNEL`(この`music.rs`が持つ、`Channel<CriticalSectionRawMutex, usize, 8>`。CORE0のボタンタスクから、押されたボタンのperson_idx(取り消し時は`CANCEL_MELODY`=5)を受け取る、唯一のチャンネルでコアをまたぐ。NeoPixelの状態は`led_pattern.rs`に、サーバー送信用のデータは`outbox.rs`にある)から受け取ったperson_idxでメロディを選び直し、`embassy_time::with_timeout`で次のノートの時刻まで待機しながら`waveform::SLOT_CHANNELS`の2つに交互に`NoteOn`を送出する。再生中に新しいイベントが来たら、鳴っている音は特に消音せずに新しいメロディの先頭から再生を始める

**ビルド/書き込み(移行後のRP2350/Pico 2 W):** `.cargo/config.toml`で`target = "thumbv8m.main-none-eabihf"`、`runner = "picotool load -u -v -x -t elf"`を設定(`elf2uf2-rs`のUF2出力はRP235xでは動作しないことをembassy-rs/embassy#4322で確認済み)。リンカには`flip-link`を使用(スタックオーバーフローのガードページ — デバッガがない環境では有用。このターゲットでも問題なくリンクできることを確認済み)。`memory.x`はRP2350のブートレイアウト(RP2040のBOOT2領域の代わりに`.start_block`/`.bi_entries`/`.end_block`セクション)を使用しています — `embassy-rp`の`rp235xa`featureが必要な`IMAGE_DEF`ブートブロックを自動的に生成してくれるため、`main.rs`側の変更は不要でした。`cargo run --release`でビルド → BOOTSELモードのPico 2 Wに`picotool`経由で書き込みます。

## サーバー(`server/`、Python + Flask)

**構成:** `Flask==2.2.5`(`Werkzeug==2.2.3`、Jinja2を同梱)に加え、本番用WSGIサーバーとして`waitress==2.1.2`を使用 — このアプリはRaspberry Pi 4上でsystemd経由で24時間365日稼働するため(`docs/deploy.md`参照)、実際にデプロイされるのは`wsgi.py`/waitressの組み合わせです。本番のPiはPython 3.7.3(Raspberry Pi OS Buster)のため、これらは3.7をサポートする最後のリリースに固定してあり、コード側も`from __future__ import annotations`で3.8以降専用の型ヒント構文(`X | Y`、`list[X]`)を避けています(`docs/deploy.md`参照)。`app.py`のFlask開発用サーバー(`python app.py`)はローカル開発用としてのみ残しています。永続化は標準ライブラリの`sqlite3`を使用(スキーマは小さなテーブル2つのみで、ORMは不要)。

**スキーマ(`schema.sql`):**
```sql
CREATE TABLE press_status (
    person TEXT PRIMARY KEY,
    last_pressed_at TEXT,        -- ISO8601、一度も押されていなければNULL
    last_pressed_date TEXT       -- 'YYYY-MM-DD'形式、リセット処理の判定に使用
);
CREATE TABLE occupancy_log (
    id INTEGER PRIMARY KEY AUTOINCREMENT,
    occupied INTEGER NOT NULL CHECK (occupied IN (0,1)),
    changed_at TEXT NOT NULL     -- ISO8601、追記専用で、削除されることはない
);
```
`press_status`は起動時に`config.PEOPLE`から(`INSERT OR IGNORE`で)初期投入されます — 家族の追加は設定変更+再起動で対応します。現在の在室状態は、専用の「現在の状態」テーブルを持たず、`occupancy_log`の最新行そのものとします(こうすることで状態のズレを防いでいます)。

**日次リセット(スケジューラなし):** 読み書きのたびに`last_pressed_date`を`date.today()`(サーバーのローカル時刻。UTCのクラウドインフラではなく自宅LAN上で動いているため、標準ライブラリの`datetime`のみで`pytz`/`zoneinfo`は不要)と比較します。`pressed_today = (last_pressed_date == today)`。押下時の書き込みは無条件のupsertであり、同日中の再押下は害のない冪等な上書きになります。

**ルーティング(`app.py`、アプリファクトリパターン):**
| メソッド | パス | 用途 |
|---|---|---|
| POST | `/api/press` | `{"person": "<id>"}` → `config.PEOPLE`に対して検証(未知なら400)、`press_status`をupsert |
| POST | `/api/cancel` | `{"person": "<id>"}` → 検証は`/api/press`と同じ。`press_status`の`last_pressed_at`/`last_pressed_date`をNULLに戻す(冪等。ボタン長押しによる取り消し) |
| POST | `/api/occupancy` | `{"occupied": true\|false}` → `occupancy_log`に追記(サーバー側での重複排除はせず、ファームウェア側のデバウンスを信頼する) |
| GET | `/api/status` | JSONスナップショット: 人物ごとの`pressed_today`/`last_pressed_at`、現在の`occupied`/`occupied_since` |
| GET | `/api/led-state` | `config.PEOPLE`と同順で1人1文字(押下済みなら`1`、そうでなければ`0`)の`"10100"`形式を`text/plain`で返す — ファームウェアがNeoPixelを同期するための軽量な表現(`docs/protocol.md`参照) |
| GET | `/` | `/api/status`と同じ`db.get_status()`のデータを使って`templates/status.html`を描画 |

`db.py`は`init_db()`、`get_status()`、`get_led_state()`、`record_press()`、`cancel_press()`、`record_occupancy()`を公開しており、ルート側は薄いまま(パース → 呼び出し → 返却/描画)にしています。`get_led_state()`は`get_status()`の結果から組み立てており、`/`・`/api/status`・`/api/led-state`はすべて同じ`get_status()`を情報源にしています(クエリ処理を各ルートに重複させない)。戻り値の型は`models.py`のdataclass(`PersonStatus`/`Status`)、設定値(`PEOPLE`、ホスト/ポート、DBパス)は`config.py`にあります。

**ページ:** `templates/base.html` + `status.html`、`<meta http-equiv="refresh" content="5">`(自宅LAN向けのダッシュボードなのでJS/WebSocketは不要) — 5人分を色付きのピル(押した/押していない)で表示し、在室状態のバナーを1つ表示(在室中/不在 + 開始時刻)。`static/style.css`で最小限のスタイリングを行います。

## 作成されたファイル
```
firmware/Cargo.toml, Cargo.lock, .cargo/config.toml, memory.x, build.rs
firmware/cyw43-firmware/   (cyw43のファームウェア/CLM/nvramのBLOB)
firmware/src/{main,secrets.rs.example,config,irqs,debounce,net,wifi,outbox,buttons,occupancy,http_client,led,led_pattern,status_poll,audio,waveform,music}.rs
                            (secrets.rsは実際のWi-Fi情報を入れるgitignore対象のファイル)
server/{requirements.txt,config.py,schema.sql,db.py,models.py,app.py,wsgi.py}
server/deploy/bath-monitor.service
server/templates/{base,status}.html, server/static/style.css
server/tests/{conftest.py,test_api.py}
server/data/.gitkeep   (bath_monitor.dbは実行時状態のためgitignore対象)
docs/{design,additional_spec,protocol,wiring,deploy}.md
schematic/             (KiCadの回路図/基板データ)
README.md, .gitignore  (firmware/target/, firmware/src/secrets.rs, __pycache__/, .venv/, server/data/*.db, .pytest_cache/, schematic/bath-monitor-backups, .DS_Store)
```

## 検証手順
**サーバー(ハードウェア不要):**
```bash
cd server && python -m venv .venv && source .venv/bin/activate && pip install -r requirements.txt
python app.py
# 別のターミナルで:
curl -X POST localhost:8080/api/press -H 'Content-Type: application/json' -d '{"person":"grandpa"}'
curl -X POST localhost:8080/api/cancel -H 'Content-Type: application/json' -d '{"person":"grandpa"}'
curl -X POST localhost:8080/api/occupancy -H 'Content-Type: application/json' -d '{"occupied":true}'
curl localhost:8080/api/status
open localhost:8080/
```
併せて確認すること: 未知の人物 → 400、不正なリクエストボディ → 400、sqliteファイル内の`last_pressed_date`を手動で過去日付にしてリセット処理を確認し、`/api/status`が`false`に切り替わることを確認する。`pytest server/tests/`を実行する。

**ファームウェア(書き込み後):** PicoをBOOTSELモードにして`cargo run --release` → USBシリアル端末を開く(`screen /dev/tty.usbmodemXXXX 115200`) → Wi-Fi接続とIPのログを確認し、その後、物理的なボタン押下によってサーバー側で`POST /api/press 200`が発生すること(Flaskのリクエストログで確認可能)、ダッシュボードのピルが1回の更新サイクル以内に緑色に切り替わることを確認する。照度センサーを覆う/覆いを外すを行い、実際の状態遷移1回につき、チャタリングによる大量発生ではなく、デバウンス済みの`occupancy_log`の行がちょうど1行だけ記録されることを確認する。オンボードLEDは、cyw43の初期化後にWi-Fi接続試行(`join`)中は点灯し、接続に成功したら約1Hzで点滅すること(サーバーを止めても点滅が続くこと)、接続に失敗したら(`secrets.rs`のSSIDをわざと間違えるなど)「ピピ」と短く2回光ることを繰り返し、次の試行で点灯に戻ることを確認する。Wi-Fi非依存の動作として、`secrets.rs`のSSIDをわざと間違えて(またはルーターを止めて)Wi-Fiに接続できない状態にしても、ボタンでNeoPixelが点灯しメロディが鳴ること、その状態で押した後にWi-Fiを復旧させると自動で再接続し、押した内容がサーバーに反映されLEDも消えないこと、接続中にルーターを止めて戻すと切断後に自動で再接続すること、Wi-Fiは生きたままサーバーだけ止めて押しても、サーバー復旧後に反映されることを確認する。ボタンを押して2秒以内に離すと、該当する人物のNeoPixelが点灯してメロディが鳴る(押している間は鳴らない)ことも確認する。長押し(約2秒)では、押下メロディは鳴らずにNeoPixelが消えて取り消し音だけが鳴り、サーバー側で`POST /api/cancel 200`が発生してダッシュボードが「Not yet」に戻ること、離したときに新たな押下として扱われないこと、Wi-Fi未接続で取り消して復旧させるとLEDが再点灯せず、サーバーにも反映されることを確認する。オーディオ(`audio.rs`/`waveform.rs`/`music.rs`)は、各ボタンを押してそれぞれ異なるメロディがスピーカーから鳴ること、再生中に別のボタン(または同じボタン)を押すと途中から新しいメロディに切り替わること、音割れがないことを確認する(メロディはプレースホルダで、attack/release/damp rateやminimum levelも仮値のため、聴感による調整もここで行う)。スピーカー接続前は、ロジックアナライザ等でGPIO16/17(BCLK/LRCLK)に常時クロックが出ていること、ボタン押下時にGPIO18(DIN)へ波形が出ることを確認する。

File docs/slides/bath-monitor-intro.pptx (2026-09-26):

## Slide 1

bath-monitor

家族の「誰がお風呂に入ったか」を見える化する家庭用IoTシステム

プロジェクト紹介 ― 課題・仕様・全体システム構成
2026年9月

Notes: bath-monitor の紹介です。今回はハードウェア(専用基板)がまだ完成していないため、何を解決したいのか、どんな仕様なのか、全体のシステム構成までをお話しします。

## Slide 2

我が家のお風呂のルールと困りごと

5人家族 ― 「最後に入った人が湯船の水を抜いて洗う」

ルール

最後に入った人が
湯船の水を抜いて洗う

でも「自分が最後かどうか」が
分からない

早すぎた

まだ入っていない人がいるのに、湯船が空になって洗われていた

1

忘れられた

もう全員入ったのに「まだ誰か入っていない」と思い込み、朝まで湯船が洗われなかった

2

続かなかった

入った人が磁石で印を付ける運用も試したが徹底されず、問題が起き続けている

5人

3

2

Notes: 我が家は5人家族で、最後に入った人が湯船の水を抜いて洗うルールです。ところが、誰が入ったかを誰も正確に把握できていないため、2種類の失敗が繰り返されていました。

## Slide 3

解決したいこと

「今日、誰がもう入ったか」を家族全員が確実に分かるようにする

記録が手間にならない

入ったら浴室のボタンを
1回押すだけ。
磁石のような「つい忘れる」
操作を減らす

1

その場で一目で分かる

押した人のLEDが点灯。
押した瞬間にメロディも鳴り
「押した」ことが分かる

2

家のどこからでも分かる

スマホやPCのブラウザで
誰が入ったか・今入浴中か
をリアルタイムに確認

3

ゴール：「全員のLEDが点いた」＝自分が最後。迷わず湯船を洗える

3

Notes: 目的は「最後に入ったのは誰か」を計算することではなく、今日誰が押した/押していないかを把握すること。全員分点いていれば自分が最後だと分かります。

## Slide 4

使い方

浴室の壁に付けたパネルのボタンを押すだけ

お風呂に入る

脱衣所の照明が点くと
照度センサーが
「入浴中」を検知

1

自分のボタンを押す

自分のLEDが自分の色で
点灯し、自分専用の
メロディが鳴る

2

間違えたら長押し

2秒の長押しで取り消し。
LEDが消え、
取り消し音が鳴る

3

毎日0時にリセット

日付が変わると
全員が「未入浴」に戻る

4

いつでも：スマホ/PCのブラウザでダッシュボードを開けば、誰が入ったか・今誰かが入浴中かが分かる

見る

4

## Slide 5

仕様：浴室パネル

浴室の壁に取り付ける箱に、ボタン・LED・センサー・スピーカーをまとめる(完成予想図)

スピーカー

ボタンを押すと人ごとに違うメロディ、取り消しでは取り消し音(I2Sアンプ MAX98357A)

Wi-Fi

自宅LANのサーバーへ送信。切れていてもパネルは単体で動く

フルカラーLED × 5

押した人：自分の色で点灯
まだの人：入浴中は白くゆっくり明滅。誰もいなければ消灯

USB

USBで給電。箱の中にはマイコン Raspberry Pi Pico 2 W(Wi-Fi内蔵)

ボタン × 5(1人1個)

押して離すと入浴済みに。長押し(2秒)で取り消し

照度センサー

脱衣所の明るさで「入浴中」を判定。明るさのしきい値は調整できる

完成予想図(イメージ)

5

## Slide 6

仕様：サーバーとダッシュボード

自宅の Raspberry Pi 4 で24時間稼働。記録を保存し、見やすく表示する

Bath Monitor

入浴中(21:32〜)

ダッシュボードのイメージ

1日単位で記録

同じ日に何度押しても記録は1回分。取り消しは長押しで

1

おじいちゃん

入浴済み

0時に自動リセット

日付を比較するだけの仕組みで、タイマー処理なしでリセット

2

おばあちゃん

まだ

お父さん

入浴済み

入退室の履歴を保存

在室/不在の変化は削除せず追記し、いつ入浴していたかを残す

3

お母さん

入浴済み

息子

まだ

5秒ごとに自動更新

自宅LAN内のスマホ/PCのブラウザで開くだけ。アプリ不要

4

6

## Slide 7

全体システム構成

浴室パネル・自宅サーバー・ブラウザの3つを自宅LANでつなぐ

浴室パネル

Raspberry Pi Pico 2 W(Rust)

- ボタン × 5
- 照度センサー
- フルカラーLED × 5
- アンプ + スピーカー
- Wi-Fi(CYW43439)

自宅サーバー

Raspberry Pi 4(Python / Flask)

- HTTP API を受け付け
- SQLite に記録
- 0時で日次リセット
- ダッシュボード(HTML)を配信
- systemd で自動起動・再起動

スマホ / PC

ブラウザのみ(アプリ不要)

- 誰が入浴済みか
- 今、入浴中か
- 5秒ごとに自動更新

パネル → サーバー：ボタン押下/取り消し・在室の変化を送信(HTTP POST)

サーバー → パネル/ブラウザ：LED状態の定期同期・ダッシュボード表示(HTTP GET)

7

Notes: MQTTなどは使わず、単純なHTTPだけでつなぎます。すべて自宅LAN内で完結し、クラウドは使いません。パネルは定期的にサーバーからLED状態を取得するので、0時のリセットや再起動後もLEDが正しい状態に戻ります。

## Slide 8

浴室パネルの内部構成

2つのCPUコアで役割を分担し、Wi-Fi通信と音の再生が互いに邪魔しない

押しボタン × 5

GPIO 2〜6

Pico 2 W(RP2350)

CORE0

- ボタン/センサーの読み取り
- LED描画(10fps)
- Wi-Fi接続管理・HTTP送信
- サーバーとのLED状態同期

CORE1(音専用)

- メロディ再生 → シンセ合成
- → I2Sへ途切れず出力

フルカラーLED × 5

GPIO 15 / PIO1

照度センサー

GPIO 26

ボタンを押したときの点灯とメロディは、Wi-Fiを使わずパネルの中だけで完結する

アンプ MAX98357A
+ スピーカー

GPIO 16〜18 / PIO2(I2S)

Wi-Fiチップ CYW43439

PIO0(SPI)

8

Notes: PIO(プログラマブルI/O)を3ブロックすべて使い、Wi-Fi・LED・音声をそれぞれDMAで駆動しています。音声はCORE1専用にして、ネットワーク処理の遅延で音が途切れないようにしています。

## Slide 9

通信の取り決め(HTTP API)

パネルとサーバーは JSON / テキストの小さな HTTP リクエストだけでやりとりする

メソッド | パス | 内容 | 意味
POST | /api/press | {"person":"father"} | ボタンを押して離した(入浴済みにする)
POST | /api/cancel | {"person":"father"} | 2秒長押し(その日の入浴記録を取り消す)
POST | /api/occupancy | {"occupied":true} | 在室状態が変化した(履歴に追記)
GET | /api/led-state | → "10110" | 1人1文字でLED状態を返す(パネルが定期取得)
GET | /api/status | → JSON | 全員の状態と在室状態のスナップショット
GET | / | → HTML | ダッシュボード(5秒ごとに自動更新)

- パネル→サーバーの送信は、届くまで(2xx応答まで)再送。オフライン中の操作も後で必ず届く
- 人の並び順(おじいちゃん・おばあちゃん・お父さん・お母さん・息子)はパネルとサーバーで共通

9

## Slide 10

設計のポイント

家族が毎日使うものなので「止まらない・取りこぼさない」を重視

Wi-Fiが切れても使える

ボタン・LED・メロディ・センサーは Wi-Fi より先に起動。通信状態に関係なく動作する

1

操作を取りこぼさない

サーバーに届けるべき操作をパネル内に保持し、つながったら届くまで再送。人ごとに最新の操作だけを送る

2

サーバーと自動で一致

パネルは定期的にLED状態をサーバーから取得。0時のリセットや再起動後も正しい表示に戻る

3

音が途切れない

音の合成と出力はCORE1専用。通信処理の遅れが音に影響しない

4

10

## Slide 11

使っている技術

ファームウェア・サーバー・基板の3つを1つのリポジトリで管理

ファームウェア

Rust(no_std)

- embassy-rp:非同期ランタイム
- cyw43 / embassy-net:Wi-Fi・TCP/IP
- reqwless:HTTPクライアント
- PIO + DMA:LED・I2S・Wi-Fi SPI
- picotool で書き込み

サーバー

Python

- Flask:Web API・画面
- SQLite:データ保存(テーブル2つ)
- waitress:本番用WSGIサーバー
- systemd:自動起動・再起動
- pytest:自動テスト

ハードウェア

KiCad

- Raspberry Pi Pico 2 W
- NeoPixel(WS2812)× 5
- MAX98357A I2Sアンプ
- CdS + LM393 光検出モジュール
- 専用基板を設計中

11

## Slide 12

現在の状況と次のステップ

済

済

済

今

次

次

設計・実装

ファームウェア/サーバー
一通り実装

サーバー稼働

Raspberry Pi 4で稼働
スマホから閲覧OK

ブレッドボード検証

Wi-Fi・送信・ボタン・
音・LED・センサー

専用基板の設計

KiCadで回路図・
基板データを作成中

基板製作・全機能確認

5個のボタン、音量、
人ごとの色など

浴室に設置

センサーのしきい値を
実際の明るさで調整

基板が完成したら全機能をチェックし、浴室に設置して家族で使い始める予定です

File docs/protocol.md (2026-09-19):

# HTTPプロトコル

`firmware/`(クライアント)と`server/`(Flaskアプリ)間の正式な契約(コントラクト)。両者はこの内容に一致させる必要があります — ファームウェア側の`PEOPLE`/`config.rs`の人物IDは、`server/config.py`の`PEOPLE`リストと完全に一致していなければなりません。

ベースURL: `http://<server-host>:8080`(ファームウェア側は`secrets.rs`の`SERVER_BASE_URL`、サーバー側は`server/config.py`の`HOST`/`PORT`で設定)。

## `POST /api/press`

デバウンス処理済みのボタン押下を、サーバーへ届けるために送信されます。Wi-Fiが切れている間やサーバーが応答しない間の押下は、ファームウェア側で「未送信」として保持され、2xxが返るまで再送されます(同じ人の複数回の押下は1回にまとまります)。サーバー側は同日中の再押下を冪等に扱うため、再送されても問題ありません。4xxが返った場合は、再送しても成功しないため破棄します。

サーバーは受信した時刻を記録するため、オフライン中の押下の記録時刻は、実際の押下時刻ではなく、送信に成功した時刻になります(深夜0時をまたぐと翌日の記録になります)。

リクエストボディ:
```json
{ "person": "grandpa" }
```

レスポンス `200 OK`:
```json
{ "status": "ok", "person": "grandpa", "date": "2026-08-30" }
```

レスポンス `400 Bad Request`(`person`が未知または欠落している場合):
```json
{ "status": "error", "message": "unknown person" }
```

## `POST /api/cancel`

ボタンの長押し(2秒以上)による、その人の今日の押下の取り消し。押下と同様に、未送信の間は保持され、2xxが返るまで再送されます。人ごとに未送信として保持されるのは最後の操作(押下か取り消し)だけなので、未送信の押下の後に取り消しがあれば、取り消しだけが送られます。サーバー側は冪等に扱います(押していない人を取り消しても何も起きません)。4xxが返った場合は破棄します。

取り消すと、その人の`last_pressed_at`は`null`、`pressed_today`は`false`に戻り、`GET /api/led-state`の該当の文字も`0`になります(ファームウェアは次の同期で反映しますが、取り消した基板自身は長押しの時点でLEDを消しています)。

リクエストボディ:
```json
{ "person": "grandpa" }
```

レスポンス `200 OK`:
```json
{ "status": "ok", "person": "grandpa" }
```

レスポンス `400 Bad Request`(`person`が未知または欠落している場合): `POST /api/press`と同じ。

## `POST /api/occupancy`

確定した(デバウンス済みの)在室状態の変化を送信します。Wi-Fiが切れている間やサーバーが応答しない間は、最後にサーバーへ届けた状態と現在の状態が異なる場合に限り、復帰後に現在の状態を1回だけ送ります(オフライン中の途中の変化は送られません)。記録時刻は、送信に成功した時刻になります。

リクエストボディ:
```json
{ "occupied": true }
```

レスポンス `200 OK`:
```json
{ "status": "ok", "occupied": true, "timestamp": "2026-08-30T21:14:03+09:00" }
```

レスポンス `400 Bad Request`(`occupied`が欠落または真偽値でない場合):
```json
{ "status": "error", "message": "occupied must be a boolean" }
```

サーバー側では同じ状態が連続して送られてきても重複排除は行いません — 送信前にデバウンスする責任はファームウェア側にあります(サーバーが受理したのに応答がタイムアウトした場合、ファームウェアが同じ内容を再送するため、同じ状態が2回記録されることがあります)。

## `GET /api/status`

ダッシュボードページで使われるJSONスナップショットで、`curl`や動作確認にも利用できます。

レスポンス `200 OK`:
```json
{
  "people": [
    { "id": "grandpa", "pressed_today": true, "last_pressed_at": "2026-08-30T19:02:11+09:00" },
    { "id": "grandma", "pressed_today": false, "last_pressed_at": null }
  ],
  "occupied": false,
  "occupied_since": "2026-08-30T19:05:00+09:00"
}
```

## `GET /api/led-state`

ファームウェアが定期的に行うNeoPixel同期処理で使われる、組み込み機器向けのコンパクトな状態表現(デバイス上でのJSONパースを避けるため)。`PEOPLE`の順序で1人につき1文字、`pressed_today`なら`1`、そうでなければ`0`。`Content-Type: text/plain`。

レスポンス `200 OK`のボディ(5人のうちgrandpaとfatherが今日押した場合の例):
```
10100
```

ファームウェアはこれを一定間隔でポーリングし(`firmware/src/status_poll.rs`を参照)、5個すべてのNeoPixelをこの状態に合わせて再調整します — これにより、サーバー側の日次リセット後にLEDが再び消灯し、またファームウェア再起動後も正しいLED状態が復元されます。

## `GET /`

`/api/status`と同じデータを使ってHTMLダッシュボードを描画します。

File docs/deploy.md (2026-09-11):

# Raspberry Pi 4上でのサーバーの24時間365日デプロイ

対象: Raspberry Pi OS(Debianベース、systemd)。サーバーは起動時に自動開始し、クラッシュ時には自動再起動するsystemdサービスとして常時稼働させます。サーバーは純粋なPython + 標準ライブラリの`sqlite3`のみで構成されているため、アーキテクチャ固有の手順は不要です。

**Pythonバージョンに関する注意**: このプロジェクトの基準としているPiはRaspberry Pi OS Busterを使用しており、**Python 3.7.3**が動いています。`server/requirements.txt`はPython 3.7をまだサポートしている最後のFlask/Werkzeug/waitressのリリースに固定されており(Flask 2.2.5 — それより新しいFlaskはPython 3.9以上が必要)、コード側も`from __future__ import annotations`によってPython 3.8以降専用の構文(`X | Y`のユニオン型や`list[X]`のような組み込みジェネリクス)を避けています。お使いのPiがより新しいPython(BullseyeやBookwormには3.9/3.11が入っています)を搭載している場合でも、これらのバージョン固定のままで問題なく動作します — OSバージョンごとに特別扱いする必要はありませんでした。

## インストール

```bash
git clone https://github.com/hasebems/bath-monitor.git ~/bath-monitor
cd ~/bath-monitor/server
python3 -m venv .venv
.venv/bin/pip install -r requirements.txt
```

`/home/pi/bath-monitor`以外の場所にcloneする場合や、`pi`以外のユーザーで実行する場合は、以下のパスを適宜調整してください。

## systemdサービス

`server/deploy/bath-monitor.service`がユニットのテンプレートです — 長期間無人稼働させるため、`app.py`のFlask開発用サーバーではなく、`server/wsgi.py`(本番用WSGIサーバーであるwaitress)を実行します。

```bash
sudo cp ~/bath-monitor/server/deploy/bath-monitor.service /etc/systemd/system/
sudo systemctl daemon-reload
sudo systemctl enable --now bath-monitor
```

状態/ログの確認:
```bash
systemctl status bath-monitor
journalctl -u bath-monitor -f
```

これで、自宅LAN上のどの端末からでも`http://<pi-hostname-or-ip>:8080/`でダッシュボードにアクセスできるようになります — ファームウェア側の`SERVER_BASE_URL`(`firmware/src/secrets.rs`)にそのアドレスを設定してください。

## コード変更後の更新方法

```bash
cd ~/bath-monitor && git pull
cd server && .venv/bin/pip install -r requirements.txt   # requirements.txtが変更された場合のみ
sudo systemctl restart bath-monitor
```

## 補足事項

- `server/data/bath_monitor.db`は再起動をまたいで永続化されます(ローカルディスク上にあり、gitignore対象です)。過去の`occupancy_log`データを残しておきたい場合はバックアップしてください。
- 押下状況の日次リセットは、Piのシステム時計/タイムゾーンが家庭の設定に合っていることに依存します(`date.today()`はローカル時刻を使用します) — 想定と違う時刻にリセットされるようであれば`timedatectl`で確認してください。
- ユニットファイル内の`Restart=always`により、クラッシュや`journalctl`で確認できる例外が発生した場合でも、手動対応なしに`RestartSec=5`以内にサービスが復旧します。

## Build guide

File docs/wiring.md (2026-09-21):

# 配線

浴室内またはその付近に設置する1枚の基板を、1台のRaspberry Pi Pico 2 Wに配線します。以下のピン番号はGPIO番号であり、`firmware/src/config.rs`と一致している必要があります。Pico 2 Wは元のPico Wとピン互換(同じ40ピン配置・同じGPIO番号)なので、これらの割り当ては元のPico Wの計画からそのまま引き継がれています。

## ボタン(5個、家族一人につき1個)

各ボタン: 片方の端子をGPIOピン(内部プルアップ付きの入力として設定)に、もう片方をGNDに接続します。押すとピンがLowになります。`PEOPLE`/`BUTTON_PINS`の順序は`server/config.py`の`PEOPLE`リストと一致させる必要があります。

| 人物インデックス | GPIO |
|---|---|
| 0 | 2 |
| 1 | 3 |
| 2 | 4 |
| 3 | 5 |
| 4 | 6 |

書き込み前に実際の配線に合わせて調整してください。

## 照度/在室センサー(1個)

GPIO26上で、(センサー基板上のコンパレータ/しきい値回路などにより)クリーンな2値のデジタル信号が得られることを前提とし、単純なデジタル入力として読み取ります。センサーがアナログレベルを出力する場合は、`firmware/src/occupancy.rs`をデジタル`Input`ではなく、しきい値定数付きの`embassy_rp::adc::Adc`に切り替える必要があります — その場合は本ドキュメントと`config.rs`の`LIGHT_SENSOR_PIN`のコメントも合わせて更新してください。

推奨部品: CdS光導電セル(LDR) + LM393コンパレータの「光検出モジュール」(Arduino向けによく売られている安価で一般的なもの) — オンボードのトリムポットでしきい値を調整でき、上記のデジタル入力の前提通りHIGH/LOWを直接出力するため、ファームウェアの変更は不要です。実機での動作は確認済みです(2026-09-20: センサーを覆うと、デバウンスされた在室状態が`POST /api/occupancy`で送られ、サーバーのダッシュボードに在室と表示される)。実際の浴室の明るさでの確認はまだしていません — 設置後にトリムポットのしきい値を確認してください。

| 信号 | GPIO |
|---|---|
| 在室センサー | 26 |

## NeoPixel(WS2812)押下インジケーター(5個、デイジーチェーン接続)

ボタン1個につきNeoPixel1個を、1本のチェーンとして配線します(LED 0の`DIN` → GPIOデータピン、LED NのDOUT → LED N+1のDIN)。順序は`BUTTON_PINS`/`PEOPLE`と同じです。PIO1(PIO0はcyw43 Wi-FiのSPIリンクで使用中)+ DMA_CH2(DMA_CH0/CH1はcyw43が使用中)で駆動します。RP2350はRP2040(PIO2個、DMA12チャンネル)よりPIOブロック数(3個)とDMAチャンネル数(16個)が多いため、この割り当てはPico 2 W上でも余裕を持って有効です。その人物が今日ボタンを押していれば人ごとに決めた色で点灯し(色は`led_pattern.rs`の`PRESSED_COLORS`)、まだ押していなければ、在室(照度センサーが on)のときだけ、白で6秒周期にだんだん明るく/暗くを繰り返し(位相をLEDごとにずらすため、光がチェーンに沿って流れて見えます。不在のときは消灯)、5個ぶんの状態は、押下の有無にかかわらず`NEOPIXEL_FRAME_INTERVAL_MS`=100ms(10fps)ごとに毎フレーム書き直されます(データ線がイベント時の1回きりにならないため、オシロで確認しやすくなります)。見え方(色や呼吸など)は`firmware/src/led_pattern.rs`だけで決まります。サーバーの`/api/led-state`から定期的に状態が再調整されます(`firmware/src/status_poll.rs`、`firmware/src/led.rs`を参照)。

| 信号 | GPIO |
|---|---|
| NeoPixelデータ(5個のチェーン) | 15 |

NeoPixelの1個目は、必ず`DIN`(入力)側にレベルシフタの出力をつないでください。`DIN`と`DOUT`を取り違えると、信号は出ていても光りません(実機の動作確認で実際に起きました)。

## MAX98357A I2Sオーディオアンプ(ボタン押下時のメロディ)

いずれかのボタンが押されるたびに、既存のLEDによるフィードバックに加えて、押したボタンごとに異なる固定のメロディ(`firmware/src/waveform.rs`/`music.rs`で合成、出力は`audio.rs`)を鳴らします。PIO2 + DMA_CH3で駆動します(下記のcyw43/NeoPixelの割り当てとは重複しません) — RP2350の3つ目のPIOブロックと余ったDMAチャンネルにより、競合なくこの機能を追加できます。

`SD`(シャットダウン)ピンと`GAIN`(ゲイン設定)ピンは別ピンです。`SD`は3V3に直結してください: 多くのMAX98357Aブレイクアウト基板(Adafruit製など)ではこのピンにオンボードのプルダウンが付いており、フローティングのままだとデフォルトでシャットダウン状態になるため、アンプを有効化するには3V3への配線が必須です(GPIOで制御する必要はなく、常時イネーブルで問題ありません)。`GAIN`はフローティング(未接続)のままにしておけばデフォルトのゲイン(9dB)になり、追加の部品は不要です。より大きい/小さい音量にしたい場合は、モジュールのデータシート記載の抵抗分圧(GNDへ直結、VDDへ抵抗経由など)に従って`GAIN`を配線してください。`VIN`は(3V3ではなく)5Vに接続します(モジュール自身がクラスD出力段まで内部でレギュレートするため)、これにより十分な音量の余裕が得られます。

| 信号 | GPIO |
|---|---|
| BCLK(ビットクロック) | 16 |
| LRC(ワード/左右クロック) | 17 |
| DIN(オーディオデータ) | 18 |

アンプとスピーカーは実機に接続済みで、ボタン押下でメロディが鳴ることを確認済みです(2026-09-19)。音量・クリッピングの有無は未確認です — 確認してください(音量は`waveform.rs`の波形テーブルのピーク振幅(フルスケールの約半分)と、`music.rs`の各ノートの`volume`で決まります。詳細はコード中のコメントを参照)。

## オンボードLED

Pico 2 W基板上のオンボードLEDは、RP2350のGPIOではなくWi-FiチップCYW43439のGPIO0(`WL_GPIO0`)につながっています。そのため外部配線は不要で、上記のGPIO割り当てとも競合しません(`firmware/src/wifi.rs`がcyw43経由で点滅させ、ファームウェアの動作確認に使います)。

## PIO / DMA割り当て一覧

| リソース | 使用箇所 |
|---|---|
| PIO0, DMA_CH0 | cyw43 Wi-Fi SPI(`net.rs`) |
| PIO1, DMA_CH2 | WS2812 NeoPixelチェーン(`led.rs`) |
| PIO2, DMA_CH3 | MAX98357A I2Sオーディオ出力(`audio.rs`) |
| USB | `embassy-usb-logger`(シリアルログ出力) |

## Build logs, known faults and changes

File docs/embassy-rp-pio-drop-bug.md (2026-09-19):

# embassy-rp 0.10.0: 複数のPIOを使うと、PIOのピンが勝手に「機能なし」に戻る

Raspberry Pi Pico 2 W(RP2350)で、複数のPIOブロックを同時に使うと、embassy-rp 0.10.0 の内部管理の不具合で、PIOに割り当てたピンが、実行の途中で黙って切り離されることがあります。この文書は、実際にそれに当たったときの調査の記録と、上流の修正がリリースされるまでの回避策をまとめたものです。同じ症状に当たった人が、原因の切り分けを短縮できることを目的にしています。

- 対象: `embassy-rp` 0.10.0(確認したのはこのバージョンのソースです)、RP2350(Pico 2 W)。RP2040でも、同じコードを使っているので起こりうると思いますが、確認していません
- 状況の確認日: 2026-09-19

## 要約

- 症状: PIOで駆動するはずのGPIOに、信号がまったく出ない。ソフトのログ上は、PIOもDMAも正常に動いている。
- 原因: `embassy-rp` が、PIOの「利用者数」と「使用中のピン」を記録する変数が、PIO0・PIO1・PIO2で共有されていた。ある `Pio` の未使用の部品をdropしただけで、別のPIOに割り当てたピンまで、機能なし(NULL)に戻される。
- 回避策: 未使用の `Common` と `StateMachine` を、dropさせずに `core::mem::forget` で捨てる。
- 上流の状況: [embassy-rs/embassy#5714](https://github.com/embassy-rs/embassy/pull/5714)「Fix PIO drop」が、2026-04-07 にマージ済みです。ただし、0.10.0(2026-03-20 公開)より後の修正で、2026-09-19 時点の crates.io の最新版も 0.10.0 なので、リリース版にはまだ入っていません。

## 環境

浴室の使用状況を記録する家庭用IoT機器で、Pico 2 W を次のように使っています。

| PIO | 用途 | ピン |
|---|---|---|
| PIO0 | CYW43439(Wi-Fi)とのSPI(`cyw43-pio`) | 内蔵(GPIO24、25、29) |
| PIO1 | WS2812(NeoPixel)5個(`embassy_rp::pio_programs::ws2812`) | GPIO15 |
| PIO2 | I2Sオーディオ出力(CORE1で動作) | GPIO16、17、18 |

- executorは `embassy_rp::executor::Executor`(CORE0)で、オーディオだけCORE1で動かしています。
- 主なクレートは `embassy-rp` 0.10.0、`cyw43` 0.7.0、`cyw43-pio` 0.10.0、`embassy-executor` 0.10.0、`embassy-time` 0.5.1 です。

## 症状

- NeoPixelのデータピン(PIO1)で、信号が出ない。オシロで見ると、0Vのままだったり、中間電位(2V前後)だったりして、状況が一定しない。
- USBシリアルのログでは、NeoPixelのタスクは正常に動いていた。起動し、PIOの初期化を終え、100msごとに `write` がDMA完了まで戻っている。
- ピンをGPIO15からGPIO14に変えても、まったく同じ症状だった。
- ボード自体は正常で、Wi-Fiも、オーディオ(PIO2)も動いていた。

## 調査の経過

調査は長くなりました。原因が2つ重なっていたためです(後述)。

1. ハードウェア(ブレッドボード、レベルシフタ、プローブ)を疑った。ピンを変えても症状が変わらなかったので、ソフト側を疑うことにした。
2. ソフトを、公式の `pio_ws2812` サンプルと突き合わせた。呼び出しの順序、割り込みの結線、DMAの要求番号、クロック分周、`GPIOBASE` を確認したが、違いはなかった。
3. NeoPixelが「イベントのときにだけ」信号を出す作りだと、オシロで捉えにくいので、10fpsで毎フレーム書き込む作りにした。それでも、症状は変わらなかった。
4. **決め手: ピンの状態を、レジスタから直接ログに出した。** これで、初めてはっきりした(次の節)。

## 決め手: レジスタを読むログ

`embassy-rp` の `unstable-pac` フィーチャを有効にして、ピン自体のレジスタを1秒ごとにシリアルへ出しました。

```rust
use embassy_rp::pac;

let pin = 14usize; // 対象のGPIO
let status = pac::IO_BANK0.gpio(pin).status().read();
let funcsel = pac::IO_BANK0.gpio(pin).ctrl().read().funcsel(); // 7 = PIO1、31 = NULL
let padoe = (pac::PIO1.dbg_padoe().read() >> pin) & 1;           // PIO1から見た出力有効
log::info!(
    "GPIO{} funcsel={} oe={} out={} in={} | PIO1 padoe={}",
    pin, funcsel,
    status.oetopad() as u8, status.outtopad() as u8, status.infrompad() as u8,
    padoe,
);
```

出力の抜粋です(実際のログを、要点だけに絞っています。この時は、切り分けのために、データピンをGPIO14に変えて試していました)。

```
led: 10 frames written
led: GPIO14 funcsel=7  oe=1 out=1 in=1 | PIO1 padoe=1
network stack ready (not yet joined to Wi-Fi)
led: 20 frames written
led: GPIO14 funcsel=31 oe=0 out=0 in=0 | PIO1 padoe=1
```

- 起動の約1秒後は、`funcsel=7`(PIO1)で、ピンは出力になっている。
- Wi-Fiチップの初期化(`net::init`)が終わった後は、`funcsel=31`(NULL)、`oe=0` に変わっている。**その後、二度と戻らない。**
- PIO1のほうは、`padoe=1` のまま、出力しているつもりでいる。パッドの機能だけが、PIOから切り離されている。
- パッドの設定レジスタ(プルや入力バッファ)は変わっていない。書き換えられたのは、機能選択(`funcsel`)だけだった。

「ソフトは正常に動いているのに、パッドがPIOにつながっていない」ことが、はっきり分かります。この「機能選択だけをNULLに戻す」動作は、`embassy-rp` の `on_pio_drop` が行うものと一致しました。

## 原因

`embassy-rp` 0.10.0 の `pio/mod.rs` では、PIOの状態が次のように保持されていました(要点のみ)。

```rust
trait SealedInstance {
    // ...
    fn state() -> &'static State {
        static STATE: State = State {
            users: AtomicU8::new(0),        // 利用者数(Common 1 + StateMachine 4)
            used_pins: AtomicU64::new(0),   // 使用中のピンの集合
        };
        &STATE
    }
}
```

これは、PIOごとに別々の状態を持つつもりの書き方です。しかし、Rustでは、ジェネリックな関数(トレイトのデフォルトメソッドも含む)の中の `static` は、型ごとに複製されず、プログラム全体で1つです。PIO0、PIO1、PIO2が、同じ `State` を共有していました。

小さなコードで確認できます。

```rust
use std::sync::atomic::{AtomicU8, Ordering};
struct State { users: AtomicU8 }
trait Inst {
    fn state() -> &'static State {
        static STATE: State = State { users: AtomicU8::new(0) };
        &STATE
    }
}
struct Pio0; struct Pio1;
impl Inst for Pio0 {}
impl Inst for Pio1 {}
fn main() {
    Pio0::state().users.store(5, Ordering::SeqCst);
    println!("Pio1 sees users = {}", Pio1::state().users.load(Ordering::SeqCst)); // 5
    println!("same address: {}", std::ptr::eq(Pio0::state(), Pio1::state()));     // true
}
```

### 今回、何が起きたか

`Pio::new` は、`users` を 5 に、`used_pins` を空にします。`Common` や `StateMachine` をdropするたびに、`on_pio_drop` が `users` を1つ減らし、**1から0に減った(最後の利用者が消えた)とき、記録にあるすべてのピンの機能をNULLに戻します。**

このファームウェアでは、次の順で起きていました(実際の数値は、CORE1側の起動のタイミングにも左右されます)。

1. `led_task` が `Pio::new(pio1)` を呼ぶ。`users` が 5、`used_pins` が空になる(それまでのPIO0のピンの記録も、消える)。
2. `let Pio { mut common, sm0, .. } = Pio::new(pio1, Irqs);` の `..` で、使わないSMが3つdropされる。`users` が 2 になる。
3. NeoPixelのピンが記録される。`used_pins` には、GPIO15(のちに14)だけが入っている。
4. `net::init` が `let mut pio = Pio::new(pio0, Irqs);` の未使用の部品(`common` と SM 3つ)を、関数を抜けるときにdropする。`users` が 2 から 1、そして 0 に減る。**0に減った瞬間に、記録にあるNeoPixelのピンが、NULLに戻される。**
5. `users` は、その後もさらに減って、アンダーフローする。デバッグビルドだと `subtract with overflow` でパニックする。リリースビルドでは、値が回って、黙って進む。

上流のPR #5714 が報告している症状(「複数のPIOをdropすると、`subtract with overflow` でパニックする」)と、同じ原因です。今回のピンが切り離される症状は、その別の現れ方だと考えています。

補足として、オーディオ(PIO2、GPIO16〜18)が無事だった理由は、`Pio::new` が `used_pins` を空にするため、その記録から外れていた(または記録のタイミングが違った)ためと考えられますが、これは推測で、確認していません。つまり、起動順に依存する、偶然の産物である可能性が高いです。

## 回避策

未使用の `Common` と `StateMachine` を、dropさせずに `core::mem::forget` で捨てます。`Pio::new` を呼ぶ、すべての場所に入れます。

```rust
// net.rs (PIO0)
let Pio { mut common, sm0, irq0, sm1, sm2, sm3, .. } = Pio::new(pio0, Irqs);
let spi = PioSpi::new(&mut common, sm0, RM2_CLOCK_DIVIDER, irq0, cs, dio, clk, dma);
core::mem::forget((common, sm1, sm2, sm3));

// led.rs (PIO1)、audio.rs (PIO2): タスクが終わらないので、common は生かしたまま
let Pio { mut common, sm0, sm1, sm2, sm3, .. } = Pio::new(pio1, Irqs);
core::mem::forget((sm1, sm2, sm3));
```

- ポイントは、`Pio { .., sm0, .. }` の `..` で捨てられる部品も、dropされることです。`sm1`〜`sm3` を明示的に受けて、`forget` する必要があります。
- 副作用はほとんどありません。ファームウェアは、PIOを終了まで使い続けるので、資源の解放が不要です。未使用のSMは、有効にしていないので、動きません。
- **この回避策で、信号が出るようになったことを確認しました。** 書き込み直して、GPIOに信号が出ました。レジスタのログで `funcsel=7` が続くことは、書き込み後に、あらためて取っていません。
- 上流の修正版(`main`)を取り込む方法もあります(`[patch.crates-io]`)。しかし、embassy系のクレートは、互いにバージョンが強く結びついていて、APIの変更に巻き込まれる恐れがあるため、今回は見送りました。

## 上流の状況(2026-09-19 時点)

- [PR #5714「Fix PIO drop」](https://github.com/embassy-rs/embassy/pull/5714)が、2026-04-07 にマージされている。PIOごとに別の `static` を持たせる修正で、上流の `main` の `mod.rs` では、`state()` が `match Self::PIO_NO { 0 => STATE_0, 1 => STATE_1, ... }` の形になっていることを確認した。
- `embassy-rp` 0.10.0 は 2026-03-20 の公開で、この修正を含まない。crates.io の最新版は、確認した時点で 0.10.0 のまま。
- [issue #6015](https://github.com/embassy-rs/embassy/issues/6015)(RP2350で、PIOを2つ以上初期化すると、`main` の終了後にタスクが止まる)は未解決。原因は特定されておらず、今回の件と同じ原因かどうかは、確認していない。
- 上流の `main` を、このファームウェアに取り込んで動かす確認は、していない(上のとおり、見送った)。

## 自分が影響を受けているかの見分け方

次の条件が重なると、疑う価値があります。

- 複数のPIOブロックを使っている(たとえば、cyw43とWS2812、または、cyw43とI2S)。
- どこかで、`Pio` の一部をdropしている。次のような形も含まれます。
  - `let Pio { common, sm0, .. } = Pio::new(...)` の `..` で、使わないSMを捨てている。
  - `Pio::new` の結果を、関数のローカルに持ったまま、関数を抜けている。
- PIOで駆動するピンに、信号が出ない、または、途中から止まる。

確認は、上の「レジスタを読むログ」を入れて、`funcsel` が、動作中にPIOの値(今回のPIO1では 7)から 31(NULL)に変わっていないかを見るのが、確実です。PIO0とPIO2の値は、RP2350のデータシートのGPIO機能表で確認してください。

## 教訓

- **原因が2つ重なっていました。** ここまでの内容は、ソフト側の原因(embassy-rpの不具合)です。これとは別に、NeoPixelのDINとDOUTを、ブレッドボードで逆につないでいました。「ソフトの不具合を直したのに、まだ光らない」状態が、ハードの原因のせいで、続いていました。信号の有無と、光るかどうかは、別々に確かめる必要があります。
- **「ソフトは正常に動いているログ」と「ピンが実際に駆動されている」は、別のことです。** タスクが動き、DMAが完了しても、パッドが切り離されていれば、何も出ません。チップのレジスタを、直接読んで確認するのが、最も早い切り分けでした。
- **`static` を、ジェネリックな関数やトレイトのデフォルトメソッドの中に書くと、型ごとには複製されません。** ライブラリの実装でも、起こりうる、Rustの落とし穴です。

## 付記

この調査と回避策の実装は、AIコーディングアシスタント(Claude Code)との共同作業で行いました。上流の状況の確認は、GitHubのページと、crates.ioの情報を参照して行っています。上に書いたバージョンや日付は、2026-09-19 時点のものです。

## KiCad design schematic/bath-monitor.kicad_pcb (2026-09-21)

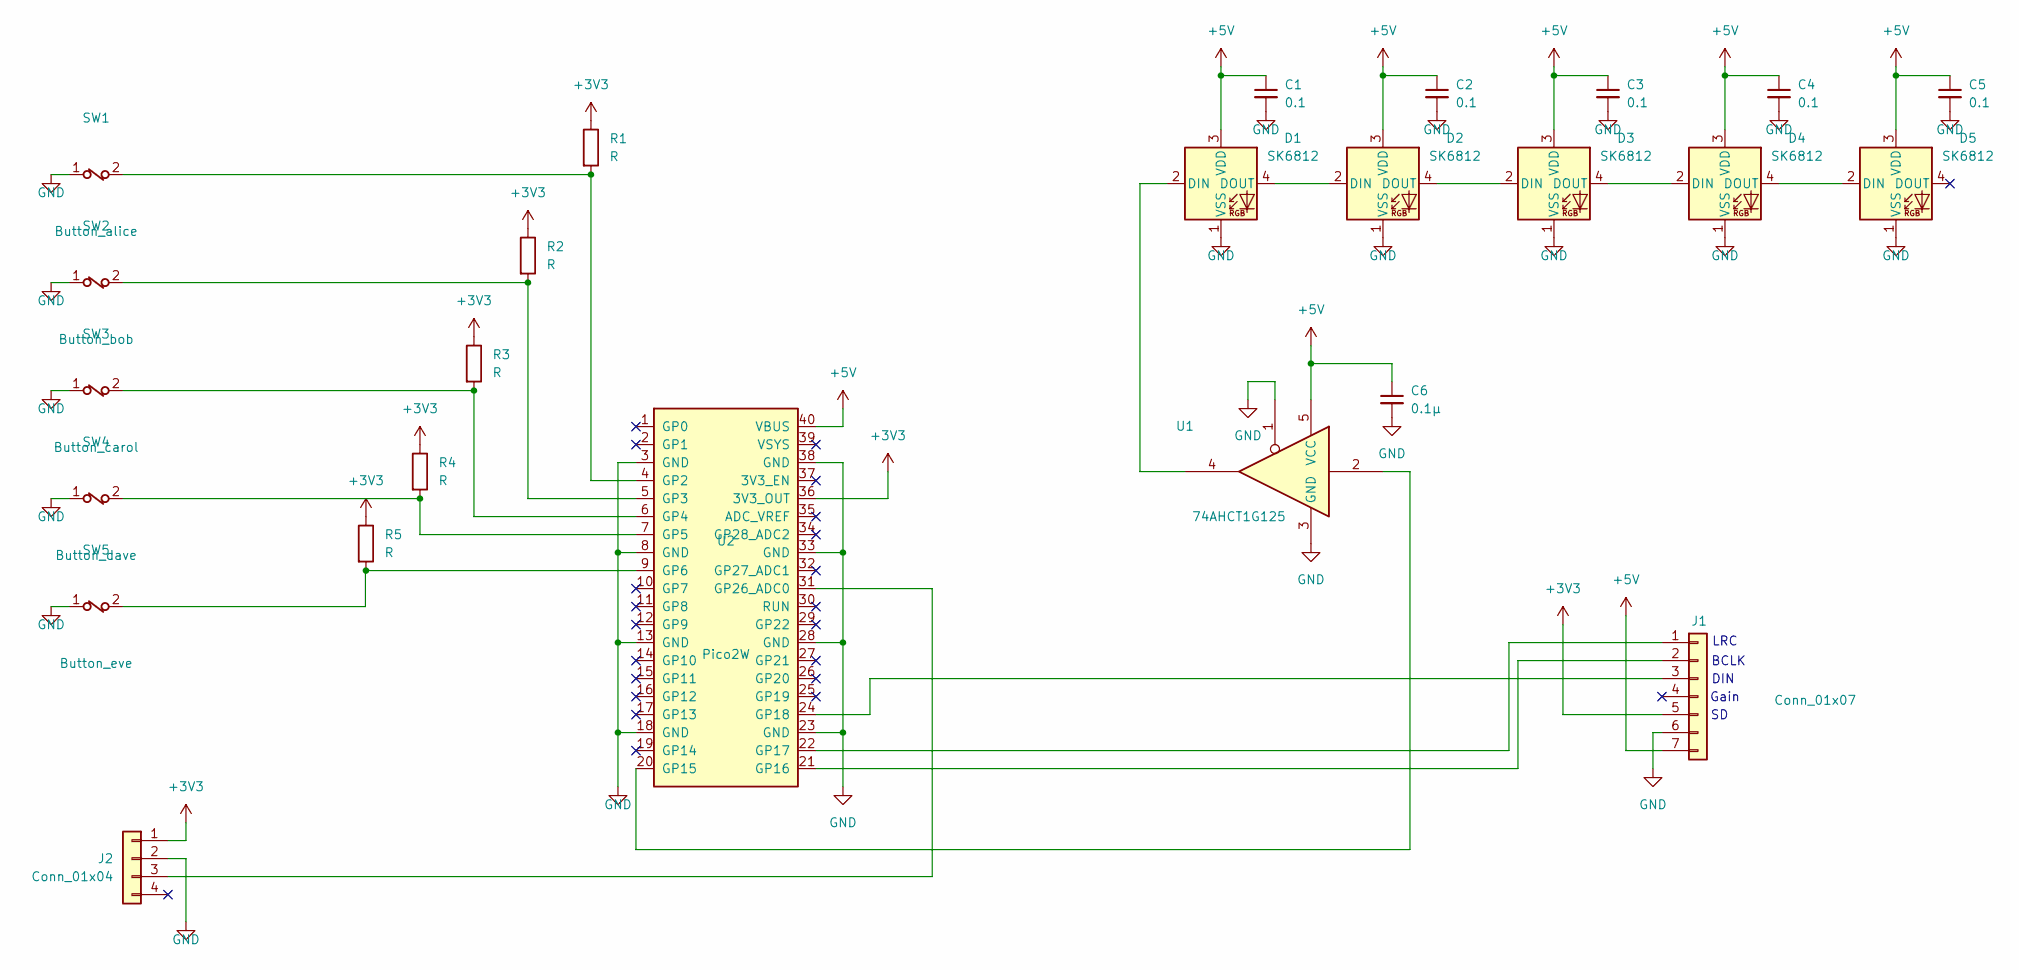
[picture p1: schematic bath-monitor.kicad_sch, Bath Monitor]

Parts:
C1, C2, C3, C4, C5: 0.1; C_0603_1608Metric_Pad1.08x0.95mm_HandSolder
C6: 0.1μ; C_0603_1608Metric_Pad1.08x0.95mm_HandSolder
D1, D2, D3, D4, D5: SK6812; LED_SK6812_PLCC4_5.0x5.0mm_P3.2mm
J1: Conn_01x07; PinHeader_1x07_P2.54mm_Vertical
J2: Conn_01x04; PinHeader_1x04_P2.54mm_Vertical
R1, R2, R3, R4, R5: R; R_0603_1608Metric_Pad0.98x0.95mm_HandSolder
SW1: Button_alice; SW_PUSH-12mm
SW2: Button_bob; SW_PUSH-12mm
SW3: Button_carol; SW_PUSH-12mm
SW4: Button_dave; SW_PUSH-12mm
SW5: Button_eve; SW_PUSH-12mm
U1: 74AHCT1G125; SOT-23-5_HandSoldering
U2: Pico2W; RaspberryPi_Pico_Common_THT

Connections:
+3V3: J1.5, J2.1, R1.1, R2.1, R3.1, R4.1, R5.1, U2.36 (3V3_OUT)
+5V: C1.1, C2.1, C3.1, C4.1, C5.1, C6.1, D1.3 (VDD), D2.3 (VDD), D3.3 (VDD), D4.3 (VDD), D5.3 (VDD), J1.7, U1.5 (VCC), U2.40 (VBUS)
GND: C1.2, C2.2, C3.2, C4.2, C5.2, C6.2, D1.1 (VSS), D2.1 (VSS), D3.1 (VSS), D4.1 (VSS), D5.1 (VSS), J1.6, J2.2, SW1.1, SW2.1, SW3.1, SW4.1, SW5.1, U1.1, U1.3 (GND), U2.3 (GND), U2.8 (GND), U2.13 (GND), U2.18 (GND), U2.23 (GND), U2.28 (GND), U2.33 (GND), U2.38 (GND)
unnamed: D1.2 (DIN), U1.4
unnamed: D1.4 (DOUT), D2.2 (DIN)
unnamed: D2.4 (DOUT), D3.2 (DIN)
unnamed: D3.4 (DOUT), D4.2 (DIN)
unnamed: D4.4 (DOUT), D5.2 (DIN)
unnamed: J1.1, U2.22 (GP17)
unnamed: J1.2, U2.21 (GP16)
unnamed: J1.3, U2.24 (GP18)
unnamed: J2.3, U2.31 (GP26_ADC0)
unnamed: R1.2, SW1.2, U2.4 (GP2)
unnamed: R2.2, SW2.2, U2.5 (GP3)
unnamed: R3.2, SW3.2, U2.6 (GP4)
unnamed: R4.2, SW4.2, U2.7 (GP5)
unnamed: R5.2, SW5.2, U2.9 (GP6)
unnamed: U1.2, U2.20 (GP15)

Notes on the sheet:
Gain
DIN
LRC
BCLK

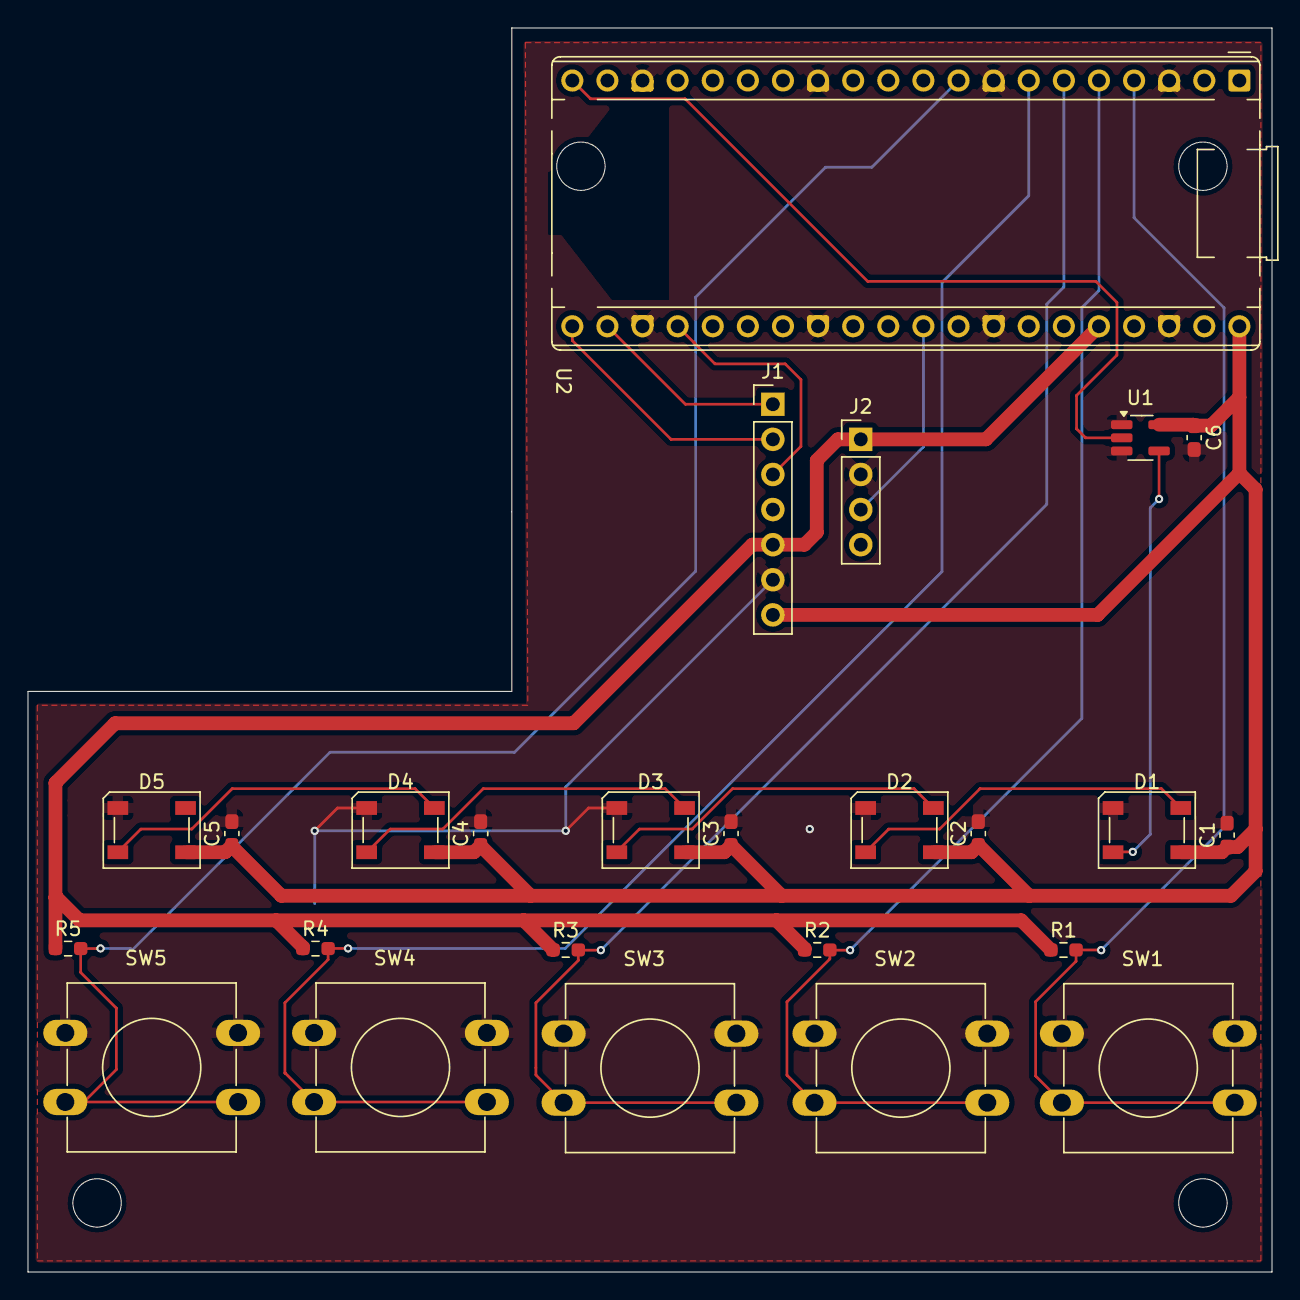
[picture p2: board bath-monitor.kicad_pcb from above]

Board: 2 copper layers, 90.0 x 90.0 mm, 25 parts (0 on the bottom side), 18 nets.

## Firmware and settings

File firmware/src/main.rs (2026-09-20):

#![no_std]
#![no_main]

mod audio;
mod buttons;
mod config;
mod debounce;
mod http_client;
mod irqs;
mod led;
mod led_pattern;
mod music;
mod net;
mod occupancy;
mod outbox;
mod secrets;
mod status_poll;
mod waveform;
mod wifi;

use embassy_executor::Spawner;
use embassy_rp::peripherals::USB;
use embassy_rp::usb::Driver;
use embassy_time::{Duration, Timer};
use panic_halt as _;

use crate::irqs::Irqs;

#[embassy_executor::task]
async fn logger_task(driver: Driver<'static, USB>) {
    embassy_usb_logger::run!(1024, log::LevelFilter::Info, driver);
}

#[embassy_executor::main(
    executor = "embassy_rp::executor::Executor",
    entry = "cortex_m_rt::entry"
)]
async fn main(spawner: Spawner) {
    let p = embassy_rp::init(Default::default());

    spawner.spawn(logger_task(Driver::new(p.USB, Irqs)).unwrap());
    // Give the USB serial host a moment to enumerate before the first logs.
    Timer::after(Duration::from_secs(1)).await;
    log::info!("bath-monitor firmware starting");

    // Everything that touches the hardware is started first and doesn't
    // depend on Wi-Fi at all (see docs/additional_spec.md, "Wi-Fi接続状態に
    // 依存しない動作"): buttons, NeoPixels, audio and the occupancy sensor
    // work from here on whether or not Wi-Fi ever connects, and even if
    // bringing up the Wi-Fi chip below hangs.
    spawner.spawn(led::led_task(p.PIO1, p.DMA_CH2, p.PIN_15).unwrap());
    audio::start(p.CORE1, p.PIO2, p.DMA_CH3, p.PIN_16, p.PIN_17, p.PIN_18);
    spawner.spawn(occupancy::occupancy_task(p.PIN_26.into()).unwrap());

    // Hardcoded pin-to-person mapping — must stay in sync with
    // config::BUTTON_PINS/PEOPLE and docs/wiring.md (PIO/GPIO field access
    // can't be driven dynamically from the config array at runtime).
    spawner.spawn(buttons::button_task(p.PIN_2.into(), 0).unwrap());
    spawner.spawn(buttons::button_task(p.PIN_3.into(), 1).unwrap());
    spawner.spawn(buttons::button_task(p.PIN_4.into(), 2).unwrap());
    spawner.spawn(buttons::button_task(p.PIN_5.into(), 3).unwrap());
    spawner.spawn(buttons::button_task(p.PIN_6.into(), 4).unwrap());

    // Wi-Fi: bring up the chip and network stack, then let `wifi_task` join
    // (and re-join) in the background; the two network tasks below just wait
    // for `wifi::is_connected()`.
    let (stack, control) = net::init(
        spawner, p.PIN_23, p.PIN_25, p.PIO0, p.PIN_24, p.PIN_29, p.DMA_CH0,
    )
    .await;

    spawner.spawn(wifi::wifi_task(stack, control).unwrap());
    spawner.spawn(http_client::sender_task(stack).unwrap());
    spawner.spawn(status_poll::status_poll_task(stack).unwrap());

    log::info!("all tasks spawned");
}

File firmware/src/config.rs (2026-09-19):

//! Non-secret configuration. Must match `server/config.py`'s `PEOPLE` order/ids
//! and `docs/wiring.md`'s pin table.

pub const PEOPLE: [&str; 5] = ["grandpa", "grandma", "father", "mother", "son"];
pub const NUM_PEOPLE: usize = PEOPLE.len();

// These pin numbers are documentation, cross-referenced by comments in
// main.rs — PIO/GPIO peripheral fields can't be indexed dynamically at
// runtime, so main.rs hardcodes `p.PIN_2` etc. and must be kept in sync
// with these values and with docs/wiring.md by hand.
#[allow(dead_code)]
/// GPIO for each person's button, same order as `PEOPLE`.
pub const BUTTON_PINS: [u8; NUM_PEOPLE] = [2, 3, 4, 5, 6];

#[allow(dead_code)]
/// GPIO for the light/occupancy sensor (digital two-state signal).
pub const LIGHT_SENSOR_PIN: u8 = 26;

#[allow(dead_code)]
/// GPIO for the NeoPixel (WS2812) data line, one chain of `NUM_PEOPLE` LEDs
/// in the same order as `PEOPLE`/`BUTTON_PINS`.
pub const NEOPIXEL_PIN: u8 = 15;

#[allow(dead_code)]
/// GPIO for the MAX98357A I2S amp's BCLK (bit clock) input.
pub const AUDIO_BCLK_PIN: u8 = 16;
#[allow(dead_code)]
/// GPIO for the MAX98357A I2S amp's LRC (word/left-right clock) input.
pub const AUDIO_LRCLK_PIN: u8 = 17;
#[allow(dead_code)]
/// GPIO for the MAX98357A I2S amp's DIN (audio data) input.
pub const AUDIO_DIN_PIN: u8 = 18;

/// Sample rate used for the I2S bit-clock timing derived from it in
/// `audio.rs`. Not a standard consumer audio rate on purpose — this is a
/// closed point-to-point I2S link (PIO to the MAX98357A) with no external
/// interop requirement, so it's chosen as 440 Hz x 100 instead: at MIDI
/// note 69 (A4 = 440 Hz exactly), the single-cycle waveform table used by
/// the additional-spec synth (`docs/additional_spec.md`) comes out to
/// exactly 100 samples with zero pitch error.
pub const AUDIO_SAMPLE_RATE_HZ: u32 = 44_000;
/// Bit depth per I2S channel; must match what `audio.rs`'s PIO program is
/// configured for (`PioI2sOutProgram`/`PioI2sOut` take this as a parameter).
pub const AUDIO_BIT_DEPTH: u32 = 16;

/// Number of samples in `audio.rs`'s shared `WAVEFORM_BUFFER`, one DMA
/// transfer's worth. CORE1 continuously streams this buffer's current
/// contents out over I2S in a loop, independent of whatever writes into it.
pub const AUDIO_BUFFER_SAMPLES: usize = 256;

/// Length of `waveform.rs`'s single-cycle sine wavetable. Exactly 100
/// because `AUDIO_SAMPLE_RATE_HZ` was chosen as 440Hz x 100, so MIDI note 69
/// (A4 = 440Hz exactly) reads this table one sample per output sample with
/// zero pitch error (see `docs/additional_spec.md`).
pub const AUDIO_WAVETABLE_SAMPLES: usize = 100;

/// The unit `music.rs`'s `NoteEvent::time`/`duration` are counted in.
pub const AUDIO_TIME_UNIT_MS: u64 = 10;

/// Per-sample envelope rate constants and silence threshold for
/// `waveform.rs`'s slots (`amplitude += (target - amplitude) * rate`,
/// applied once per sample at `AUDIO_SAMPLE_RATE_HZ`). These are
/// placeholder values, not yet tuned by ear on real hardware — see the
/// "未決定事項" list in `docs/additional_spec.md`.
pub const AUDIO_ATTACK_RATE: f32 = 0.01;
pub const AUDIO_RELEASE_RATE: f32 = 0.002;
pub const AUDIO_DAMP_RATE: f32 = 0.05;
pub const AUDIO_MINIMUM_LEVEL: f32 = 0.001;

/// `led.rs` writes the whole NeoPixel chain once per frame, every frame,
/// whether or not anything changed: 100 ms = 10 fps. So the data line is never
/// idle for long (a single burst per event is hard to catch on a scope, and a
/// stray glitch on the line is corrected by the next frame), and a change
/// shows up within one frame.
pub const NEOPIXEL_FRAME_INTERVAL_MS: u64 = 100;

pub const BUTTON_DEBOUNCE_MS: u64 = 50;
/// Holding a button this long (after the debounced press) cancels that
/// person's press for today instead — see `buttons.rs`.
pub const BUTTON_LONG_PRESS_MS: u64 = 2000;
pub const OCCUPANCY_DEBOUNCE_MS: u64 = 2000;

/// Half of the onboard LED's blink period (on for this long, then off for
/// this long) — see `wifi.rs`. 500ms gives a 1Hz blink.
pub const ONBOARD_LED_BLINK_HALF_PERIOD_MS: u64 = 500;

/// Onboard LED "join failed" pattern (see `wifi.rs`): two short flashes, each
/// on for this long and off for this long...
pub const ONBOARD_LED_FAIL_FLASH_MS: u64 = 100;
/// ...then off for this long before the pair repeats.
pub const ONBOARD_LED_FAIL_PATTERN_GAP_MS: u64 = 1600;

/// Upper bound for a whole HTTP request to the server (connect + send +
/// response), after which it's abandoned and treated as failed so the
/// sender/poll tasks can never hang on an unreachable server.
pub const SERVER_REQUEST_TIMEOUT_SECS: u64 = 10;

/// How long `http_client.rs` waits before re-trying a POST that failed
/// while Wi-Fi is still up (e.g. the server is down).
pub const SEND_RETRY_INTERVAL_SECS: u64 = 5;

/// After a successful `join`, how long `wifi.rs` tolerates the link not
/// being reported up yet before it gives up on that association and re-joins.
pub const WIFI_LINK_UP_GRACE_SECS: u64 = 10;

/// Longest a single `join` attempt in `wifi.rs` may take before it's
/// abandoned and treated as failed. cyw43's `join` has no timeout of its own
/// and can wait forever if the chip never reports an outcome.
pub const WIFI_JOIN_TIMEOUT_SECS: u64 = 20;

/// How often the firmware polls `GET /api/led-state` to reconcile NeoPixels
/// with the server's daily-reset state.
pub const LED_SYNC_INTERVAL_SECS: u64 = 30;

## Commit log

2026-08-30 Add bath-monitor: Pico W firmware + Flask server
    Tracks which family members have pressed their bath button today and
    whether the bath is currently occupied. A Raspberry Pi Pico W reads 5
    buttons and a light sensor, drives a NeoPixel per button, and reports
    over Wi-Fi/HTTP to a Flask server on the home LAN that persists state
    in SQLite and serves an auto-refreshing dashboard.
    Claude-Session: https://claude.ai/code/session_01VuC92adHfXBUMhBYm1LQWZ
2026-09-01 Add Raspberry Pi 4 deployment: waitress + systemd service
    The server runs 24/7 on a Raspberry Pi 4, so add a production WSGI
    entry point (wsgi.py, waitress) and a systemd unit for auto-start and
    crash restart, with install/update steps in docs/deploy.md. app.py's
    Flask dev server remains for local development only.
    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
2026-09-01 Improve dashboard for mobile: shorter timestamps, safer layout CSS
    Timestamps now drop microseconds when stored and render as a compact
    MM/DD HH:MM via a short_time Jinja filter, instead of a raw
    ISO8601+offset string that was too long for narrow screens. Also
    harden the CSS (box-sizing: border-box, simplified pill layout, a
    separate right-aligned time line, overflow-wrap/overflow-x safety
    nets) against long text overflowing the mobile-width dashboard.
    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
2026-09-01 Support Python 3.7 (the Pi's actual Python version)
    The Raspberry Pi runs Python 3.7.3 (Raspberry Pi OS Buster), which
    can't install Flask 3.1.3 (requires 3.9+) and would also fail at
    import time on the `str | None` / `list[X]` type-hint syntax used in
    app.py/db.py/models.py (Python 3.8+ only). Pin requirements.txt to the
    last Flask/Werkzeug/waitress releases supporting 3.7, and defer
    annotation evaluation with `from __future__ import annotations` so
    the modern-looking type hints stay valid on 3.7. Verified against a
    Python 3.9 venv (closer to 3.7 than this dev machine's 3.14, which
    can't even import Werkzeug 2.2.3) — all 7 tests pass, and wsgi.py
    (waitress) boots correctly.
    Co-Authored-B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
2026-09-01 Update README status: server verified on the real Pi
    The server is now deployed and confirmed working on the Raspberry Pi
    4 (dashboard checked from a phone on the home LAN) — the README
    previously said neither side had touched real hardware yet.
    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
2026-09-03 RP2350に変更した
2026-09-11 schematicの追加
    [bath-monitor.kicad_pcb, bath-monitor.kicad_sch]
2026-09-11 Audio処理を追加した
2026-09-11 docの更新、日本語化
2026-09-11 .gitignoreにschematicのbackup追加
2026-09-18 Audio処理を別coreで動作するようにした
2026-09-18 ドキュメント整備
2026-09-18 kicadの回路作成
    [bath-monitor.kicad_sch]
2026-09-18 ボタンを押したらcoreを跨いでメッセージを送る処理追加
2026-09-18 音楽データを再生できるようにする
2026-09-19 ドキュメントの更新
2026-09-19 wifi繋がらなくても動作するように修正
2026-09-19 onboard LEDの点滅パターンをwifi状況に応じて変えるようにした
2026-09-19 長押しでキャンセルする仕様追加
2026-09-19 ボタンを離した時に on 扱いにする
2026-09-19 neopixelを周期的に書く＆embassyのバグ対応
2026-09-19 neopixelの光り方の仕様を変更した
2026-09-20 LEDの点灯パターンを変える＆events.rs削除
2026-09-21 呼吸のLED Patternを調整した
2026-09-21 kicad で基板データ作成
    [bath-monitor-B_Cu.gbl, bath-monitor-B_Mask.gbs, bath-monitor-B_Paste.gbp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]
2026-09-26 ログ出力の説明を追記した
2026-09-26 パワポ資料を作成した
2026-10-03 曲データを変更した
2026-10-03 NeoPixelをSK6812RGBWに変更し、呼吸を全LED同じ位相にした
    - led.rs: embassy-rpのRgbwPioWs2812(GRBW、1個32ビット)で駆動
    - led_pattern.rs: 色をRGBW<u8>にし、呼吸の白は内蔵の白LEDで出す
    - 押した人が色で点灯すると流れが途切れるため、LEDごとの位相のずらし
    (BREATH_PHASE_STEP_MS)をやめ、全員同じ位相で呼吸させる
    - docs/CLAUDE.md/README.mdの記述を合わせて更新
2026-10-03 白の呼吸を1秒周期・明るさ4〜16に決定し、50fpsにした
    - 呼吸の周期を6秒から1秒に短くした
    - 最小の明るさをBREATH_FLOOR=4にし、1段の差が目立つ暗い範囲を使わない
    (時間方向のディザリングも試したが、暗いところでちらつくため不採用)
    - NeoPixelのフレーム周期を100ms(10fps)から20ms(50fps)にした
    - SK6812RGBW 5個の実機で確認し、この見え方を仕様として確定。docsに経緯を記載
2026-10-03 パワポ資料を更新した
2026-10-10 最後の1人の専用メロディを追加し、日次リセットを朝5時(29時)にした
    - ファーム: 5人全員が押下済みになった押下では、その人の曲の代わりに FINAL_MELODY を鳴らす
    - サーバー: 1日の区切りを DAY_START_HOUR=5 とし、0時〜5時はダッシュボードで前日の24時〜28時台として表示する
2026-10-10 本体回路を作成し基板発注した
2026-10-11 server側のフォルダの説明修正
2026-10-12 曲データを更新
2026-10-12 基板の試作機で運用開始し、動作検証結果と今後の検討事項をドキュメントに反映した
2026-10-17 web pageの日本語化
2026-10-17 書類などの更新
2026-10-17 readme.md に写真、リンクなどを追加した
2026-10-22 ファームの状況に内容を合わせた
2026-11-03 コメントを簡略化した
